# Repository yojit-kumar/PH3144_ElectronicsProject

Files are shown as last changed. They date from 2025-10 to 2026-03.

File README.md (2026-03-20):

# Precision Closed-Loop AC Power Controller using PID Algorithm

**Course:** PH3144 Electronics-I with Lab

**Status:** Finished (with incomplete code implementation)

A project to design and build a closed-loop AC power controller using a PID algorithm to deliver a precise, stable power output to a load.

## Team Members & Responsibilities
* **Uday Pratap Bais (20231267):** Hardware Lead (Electrical), Design Lead.
* **Yash Dadhwal (20231287):** Software Lead (Algorithm), Testing, Software Integration.
* **Yojit Kumar (20231289):** Hardware Lead (Electronics), Documentation Lead.

## Project Structure
* **/docs:** Contains all project documentation, including the report, component datasheets, and images.
* **/hardware:** Contains hardware design files (schematics, PCB layouts from KiCad).
* **/src:** Contains all Arduino source code, organized by testing phase.
* **/dump:** Put anything and everything we find before the finalizing of the project, It may later get sorted and moved to the relavant folders.

## Getting Started
1.  Clone the repository: `git clone https://github.com/yojit-kumar/PH3144_ElectronicsProject`
2.  Install the required Arduino libraries:
    * `EmonLib`
    * `LiquidCrystal_I2C`
    * `Adafruit_ADS1X15`
3. Use the calibiration codes in the `src/` directory to calibirate the measurement components
4. Run the test codes from the same directory.
---

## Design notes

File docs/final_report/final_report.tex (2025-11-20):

\documentclass[11pt]{article}

%Packages
\usepackage[a4paper, margin=1in]{geometry}

\usepackage{hyperref}
\usepackage{amsmath, amssymb}
\usepackage{siunitx}
\usepackage{romannum}

\usepackage{bookmark}
\usepackage{booktabs}
\usepackage{indentfirst}
\usepackage{multirow}
\usepackage{float}

\usepackage{titlesec}

\usepackage{graphicx}
\usepackage{subcaption}
\usepackage{tikz}
\usetikzlibrary{shapes.geometric, arrows, positioning}
\usepackage[american]{circuitikz}
\usepackage{listings}
\usepackage{xcolor}

\definecolor{codegreen}{rgb}{0,0.6,0}
\definecolor{codegray}{rgb}{0.5,0.5,0.5}
\definecolor{codepurple}{rgb}{0.58,0,0.82}
\definecolor{backcolour}{rgb}{0.95,0.95,0.92}

\lstdefinestyle{mystyle}{
    backgroundcolor=\color{backcolour},   
    commentstyle=\color{codegreen},
    keywordstyle=\color{magenta},
    numberstyle=\tiny\color{codegray},
    stringstyle=\color{codepurple},
    basicstyle=\ttfamily\footnotesize,
    breakatwhitespace=false,         
    breaklines=true,                 
    captionpos=b,                    
    keepspaces=true,                 
    numbers=left,                    
    numbersep=5pt,                  
    showspaces=false,                
    showstringspaces=false,
    showtabs=false,                  
    tabsize=2
}
\lstset{style=mystyle}

\newcommand*{\titleGP}{\begingroup
	\centering % Center all text
	\vspace*{\baselineskip} % White space at the top of the page

	\rule{\textwidth}{1.6pt}\vspace*{-\baselineskip}\vspace*{2pt} % Thick horizontal line
	\rule{\textwidth}{0.4pt}\\[\baselineskip] % Thin horizontal line
	{\LARGE Project Report}\\[0.2\baselineskip] % Title
	\rule{\textwidth}{0.4pt}\vspace*{-\baselineskip}\vspace{3.2pt} % Thin horizontal line
	\rule{\textwidth}{1.6pt}\\[2\baselineskip] % Thick horizontal line

	\vspace*{2in}
    
    	\Huge Precision Closed-Loop AC Power Controller using PID 
    	
	\vspace*{2in}

	\Large Name: Yojit Kumar\\
	\vspace*{0.2in}
	\Large Reg. No.: 20231289\\
	\vspace*{0.2in}
	\Large Course Code: PH3144\\
	\vspace*{0.2in}
	\Large Group: \#23\\

\endgroup}

\makeatletter
\let\latexps@plain\ps@plain
\newcommand{\frontmatter}{\let\ps@plain\ps@empty\pagestyle{empty}}
\newcommand{\mainmatter}{%
  \let\ps@plain\latexps@plain\pagestyle{plain}%
  \clearpage
  \pagenumbering{arabic}}
\makeatother

\begin{document}
\frontmatter
\titleGP
\clearpage

\mainmatter
\section{Introduction}
In any modern electric system, especially in labs, precise control over the power delivered to an electrical appliance/device is important for efficiency, stabilty and protection of devices. What we've tried to do is to precisely control the electrical power of any device. We are using a simple light bulb for the ease of demonstration. But in theory, we can implement this on any device connected to AC Mains.

Our device measures the current and voltage input for an electric load and allows us to fix a power in the working range of the appliance. We control this with a technique called \emph{phase-angle fired control}, where the firing  angle of a thyristor (Triac) is adjusted to control the portion of the AC Waveform delivered to the load.

For an electric bulb, this works as a dimmer for the system, allowing us to observe the difference. But a simple dimmer is an open-loop control, whilst we have implemented a closed-loop approach with help of \emph{PID}. You cannot ask the dimmer to set the bulb to run at $\SI{50}{\watt}$. You can only set it to 50\% effort, but you can't be sure. It is also susceptible to disturbances. If there is an increase in the voltage in the circuit, the dimmer doesn't know that, and the bulb will light brighter.

A closed-loop control is better because it uses the feedback to compare the result. We are constantly measuring the current and voltage to find the actual Power and compare it to the set-point to dynamically adjust the firing angle based on the feedback.

\section{Design}

\subsection{Block Diagram}
\begin{figure}[h!]
\centering
\begin{tikzpicture}[
    auto,
    block/.style={rectangle, draw, fill=blue!20, text width=6em, text centered, rounded corners, minimum height=4em},
    line/.style={draw, -latex'}
]

% Place the nodes
\node [block] (ui) {User Interface (UI)};
\node [block, right=2cm of ui] (arduino) {Controller (PID Logic)};
\node [block, below=2cm of arduino] (control) {AC Control System (Muscle)};
\node [block, right=2cm of arduino] (measure) {Measurement System (Senses)};
\node [block, below=2cm of measure] (load) {AC Load};

% Draw the lines (arrows)
\path [line] (ui) -- node [above] {Setpoint} (arduino);
\path [line] (arduino) -- node [left] {Control Signal} (control);
\path [line] (control) -- (load);
\path [line] (load) -- node [left] {Feedback} (measure);
\path [line] (measure) -- (arduino);

\end{tikzpicture}
\caption{Block Overview of the Closed-Loop Power Controller}
\label{fig:block_diagram}
\end{figure}

We divide our system into smaller task-specific parts to better understand our system. First is the User Interface (UI), it allows us to display the results and also fix a set-point for the system. The Controller (here Arduino) is the brain of the whole system, running the PID logic, and controlling all the other components of our project. The Measurement System consists of some simple sensors that allow us to take current and voltage measurements and send these to the Controller. The AC Control is the muscle of the system, it controls the parameters to maintain the set-point as dictated by the Controller.

\subsection{Hardware Design}

\begin{figure}[H]

\caption{KiCad Schematics for the whole working the circuit}
\end{figure}

\subsubsection{Measurement Module}
This module is responsible for providing the critical feedback to the controller. The major components of the measurement module are:
\begin{enumerate}
	\item \underline{ZMPT101B Voltage Sensor Module}

		This active module safely steps down the $230\si{\volt}$ AC mains voltage to a low-voltage, isolated AC sine wave. Its onboard op-amp circuit biases this signal around a $2.5\si{volt}$ DC offset, making it safe for the low-voltage components to read.

	\item \underline{SCT-013-030 Current Sensor}

		A non-invasive current transformer that clamps around the live wire. It outputs a small AC voltage that is directly proportional to the AC current flowing to the load. This signal is also biased at $2.5\si{\volt}$ using an external voltage divider.

	\item \underline{ADS1115 16-bit  ADC Module}

		This is a high-precision, 16-bit Analog-to-Digital Converter. It is connected to the Arduino via the I2C bus (A4/A5). The Arduino's built-in 10-bit ADC is too noisy and has insufficient resolution for a "precision" controller. The 16-bit ADS1115 provides high-accuracy, low-noise measurements.
\end{enumerate}

\subsubsection{AC Control Module (Muscle)}
This component is the  high-voltage part of the circuit that controls the power flow. The major components that make up the AC Control Module are:
\begin{enumerate}
	\item \underline{MOC3023M (Triac Driver Optocoupler)}

		This chip is the safe bridge between the Arduino and the Triac. It receives a low-voltage $5\si{\volt}$ "fire" command from the Arduino (on pin D7) and uses an internal light-activated switch to trigger the high-voltage Triac.
		
		This provides galvanic isolation. It is the most important safety component, creating a physical air gap between the $230\si{\volt}$ AC circuit and the 5V logic circuit, protecting the Arduino and the user from lethal voltage.
	
	\item \underline{BTA41600B (Triac)}

		This is the heavy-duty, high-power AC switch. When it receives the trigger signal from the MOC3023M, it "latches" ON and conducts current to the light bulb. It automatically turns itself OFF (resets) at the end of every AC half-cycle when the current drops to zero.

		This is the component that actually controls the power. By precisely timing when this switch is turned on within each $10\si{\milli\second}$ half-cycle, we can control the total energy delivered to the load.

	\item \underline{PC814 (AC-Input Optocoupler)}

		This chip functions as our Zero-Crossing Detector (ZCD). Its AC input side watches the sine wave from the step-down transformer. At the precise moment the wave crosses its center point, the optocoupler's internal LED turns off, and triggers the phototransistor on the output side. This interrupt signal pulls down the output PIN\_4 that is connected to $+\SI{5}{\volt}$ of the Arduino.

		This signal is connected to the Arduino's hardware interrupt pin (D2). It provides a perfect timing pulse 100 times per second, synchronizing the Arduino's code with the AC line.	
\end{enumerate}

\section{Methodology}
In order to control the high-voltage current passing through the load to precisely change the power. We are using \emph{Phase Angle Control} using the \textbf{Triac}. The method requires us to change the gate voltage to the triac to control the current through the heavy load.
\begin{figure}[hbt]
	\centering
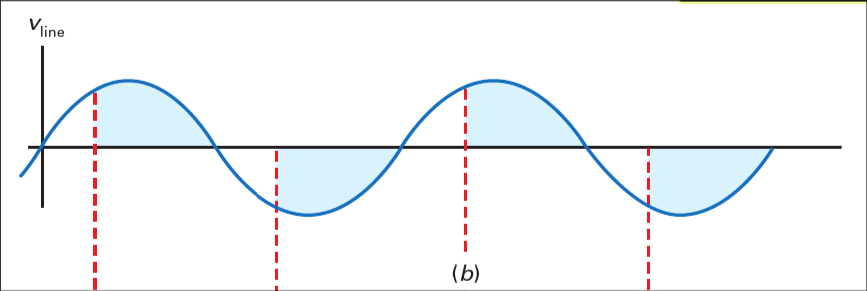
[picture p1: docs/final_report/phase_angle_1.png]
	
	\caption{Line voltage for the triac \emph{Ref: Malvino \& Bates Pg. 549}}
	\label{fig:phase_angle_1}
\end{figure}

\begin{figure}[hbt]
	\centering
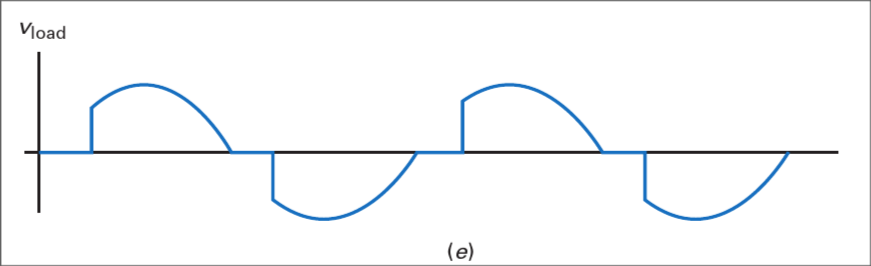
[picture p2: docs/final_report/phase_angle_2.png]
	
	\caption{Voltage across a load connected to the triac \emph{Ref: Malvino \& Bates Pg. 549}}
	\label{fig:phase_angle_2}
\end{figure}

\autoref{fig:phase_angle_1} shows the line voltage. When the triac is triggered, the triac starts conducting. It basically means the triac is on, and it will remain on until the line voltage goes back to zero then it turns off again. \autoref{fig:phase_angle_2} shows us the voltage across the load during this process. This turning on and off happens for every half-pulse of AC passing through the triac. Thus, the triac is switches its state around 200 times a second.

\begin{figure}[hbt]
	\centering
	\begin{subfigure}[t]{0.5\textwidth}	
		\centering
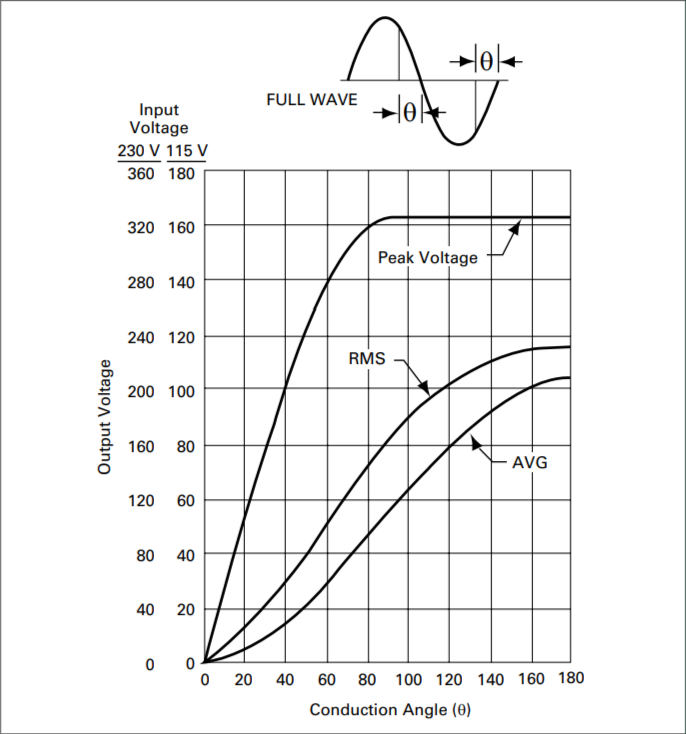
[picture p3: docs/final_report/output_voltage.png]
		
		\caption{Voltage of Full-Wave Phase Angle Control (Sinusodial)}
		\label{subfig:subfig_1}
	\end{subfigure}%
	\begin{subfigure}[t]{0.5\textwidth}
		\centering
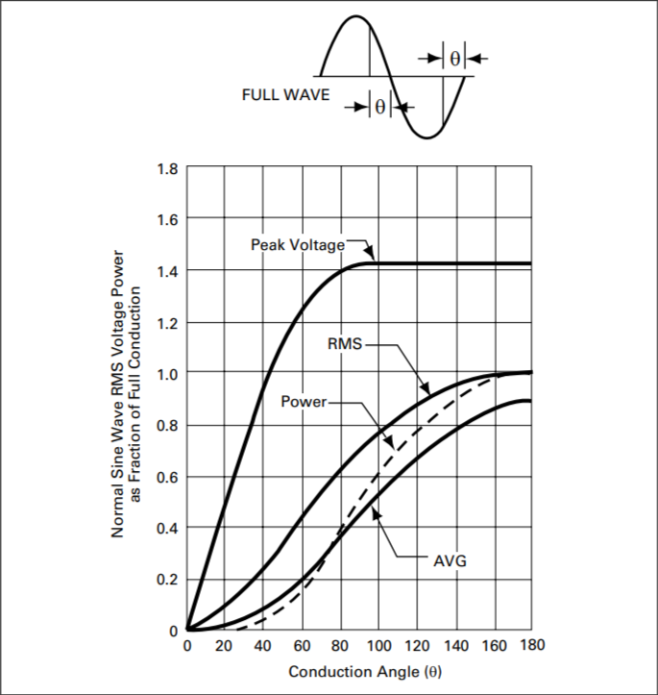
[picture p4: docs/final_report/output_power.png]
		
		\caption{Power of Full-Wave Phase Angle Control}
		\label{subfig:subfig_2}
	\end{subfigure}
	\caption{Voltage \& Power Curves for different $\theta$ \emph{Ref: Littlefuse AN1003 datasheet}} 
	\label{fig:power_curve}
\end{figure}

In \autoref{fig:power_curve}, $\theta$ is the conduction angle which is equivalent to $\pi - \theta_{\mathrm{firing}}$. $\theta_{\mathrm{firing}}$ is proportional to the firing delay. Thus, we can use the curves to study how the power or voltage may vary across the load as we change the firing delay.
But, as we are working with a closed-loop feedback system we don't need to refer to the curve, our algorithm is supposed to give us a correction just based on the error from the set point.

In order to find this error term, we need to find the real-time value of the power first. For which we are using a voltage sesing module (\emph{ZMPT101B}) and a current sensing module (\emph{SCT-013-030}), and both of these are connected to an external Analog-to-Digital Convertor(ADC) (\emph{ADS1115}) which is there to give us a better resolution than the onboard ADC of the Arduino Board.

Another important part of controlling the AC power and setting a firing delay is to actually know when the AC pulse starts. Because of how a triac functions it will auto turn-off at the end of each half cycle but we need to know the starting point. This starting point is detected using a zero-crossing detector that we have created using a step-down transformer and a AC input optocoupler (\emph{PC814}). We have also attached a basic I2C display to as a part of our user interface to display the power, voltage and current information in real-time.

\section{Implementation}

The project was designed with two separate perfboards:high-voltage perfboard as in \autoref{fig:high_voltage} and a low-voltage perfboard \autoref{fig:low_voltage}. This was created to keep in mind the safety of low volage components, and over safe handling of the project. We've also used optocouplers for the same reason; to create circuit isolation.

\begin{figure}[hbt]
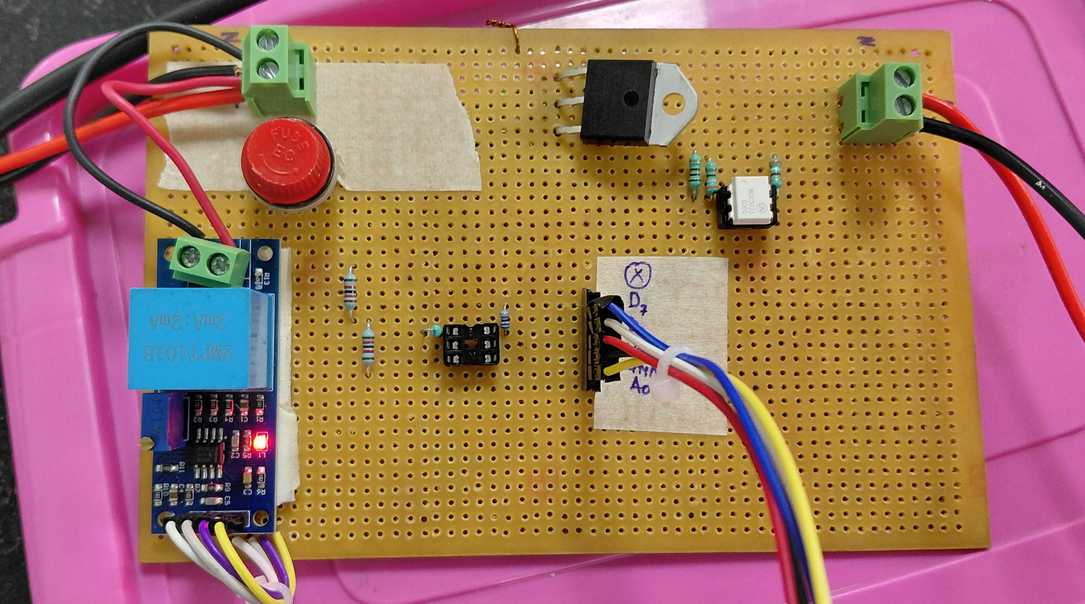
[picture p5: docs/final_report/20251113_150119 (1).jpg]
	
	\caption{\textbf{This is the high-voltage perfboard.} AC-In is from the left side which passes to the triac in the middle and load connected to the rightmost connetion point. Triac is connected to the \emph{MOC3023M} IC. The \emph{ZMPT101B} module at the left has a stepdown transformer visible to us as a blue cube. The empty IC base is supposed to hold the \emph{PC814} IC which is the AC input optocoupler, a part of the zero-crossing detector. All connections are soldered at the back and terminate at the jumper base in the middle, which we connect to the low voltage perfboard.}
	\label{fig:high_voltage}
\end{figure}

There is an extra component of the project on the breadboard as seen in \autoref{fig:zcd}. It is a zero-crossing detector made using \emph{PC814} IC and a bridge rectifier. The purpose of this circuit is to provide the required interrupt signal as seen in \autoref{fig:interrupt_signal}. This was created as a fix for a bug in our earlier designs. We will talk more on this in the debugging sections.

\begin{figure}[hbt]
	\begin{subfigure}[t]{0.45\textwidth}
	\flushleft
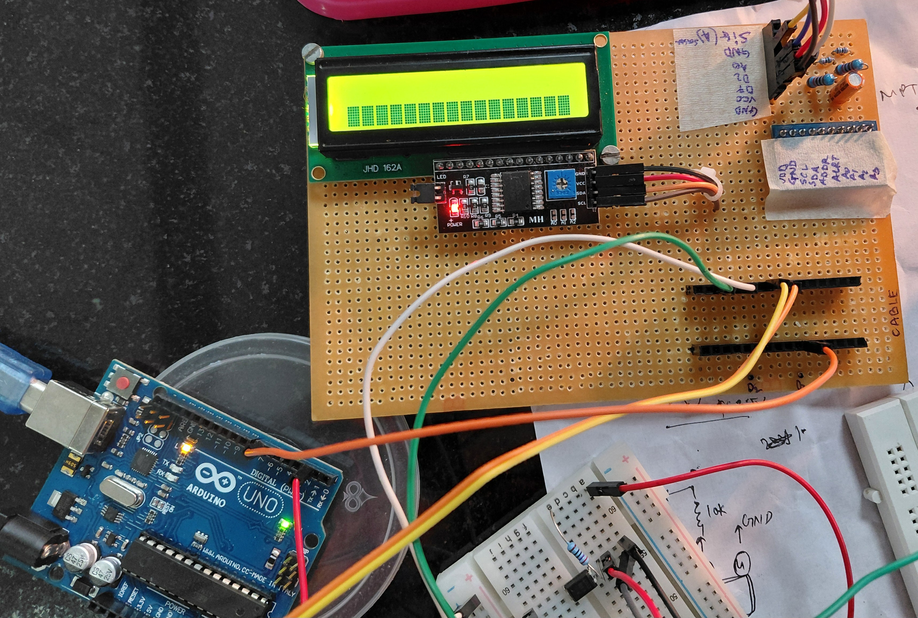
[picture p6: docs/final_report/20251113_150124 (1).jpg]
	
	\caption{\textbf{This is the low-voltage perfboard.} Jumper connections from the first perfboard and the current sensor module join at the top-right. There are voltage dividers and a clamper at the top for the ac-signal from the current-sensor module. The I2C display module is connected on top-left. And all connections terminate at the jumper base at the bottom, that connects to the \emph{Arduino UNO}}
	\label{fig:low_voltage}
	\end{subfigure}
	\hfill
	\begin{subfigure}[t]{0.45\textwidth}
	\flushright
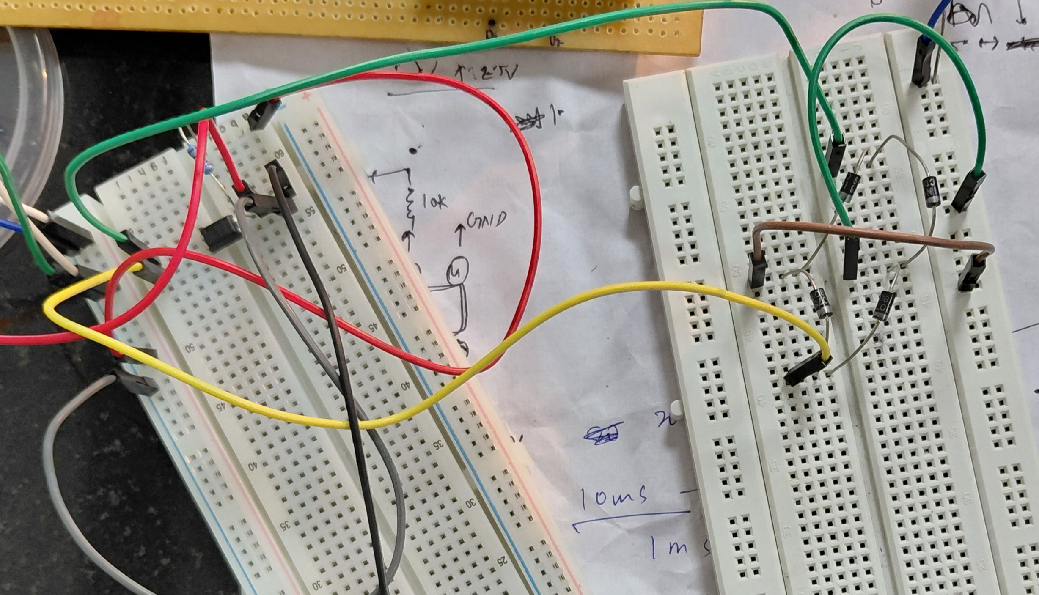
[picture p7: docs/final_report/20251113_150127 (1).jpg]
	
	\caption{This is the zero-crossing detector fix we created. The right breadboard has a bridge-rectifier which is connected to a voltage output of a stepdown 12V transformer. The rectified signal is passing to the \emph{PC814} IC on the breadboard at the right. This simply triggers at the start of each pulse half-cycle and sends a signal to the \emph{Arduino UNO}}
	\label{fig:zcd}
	\end{subfigure}
	\caption{Low-voltage Circuit}
\end{figure}

\begin{figure}[hbt]
	\centering
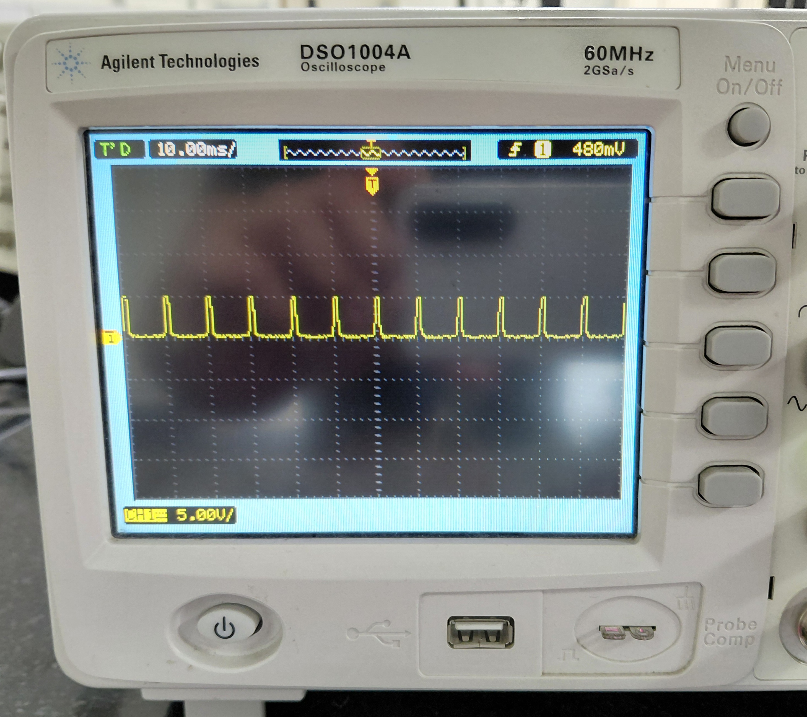
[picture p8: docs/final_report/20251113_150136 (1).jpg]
	
	\caption{This is the output for the interrupt signal from the zero-crossing detector being fired. We have a pulse/signal every $\SI{10}{\milli\second}$ as seen on the oscilloscope.}
	\label{fig:interrupt_signal}
\end{figure}

\section{Software}
The code that we've written for the project is in C++, it integrates all hardware components into a single, event-driven closed loop system.

We've have used some libraries for the operation of certain sensors, or simply the PID algorithm.

\begin{enumerate}
	\item \verb|<Wire.h>|: This is for the I2C communication, allowing us to use the \emph{ADS1115} and the LCD Display.

	\item \verb|<Adafruit_ADS1X15.h>|: It's a high level interface, specifically for the \emph{ADS1115} IC. It makes the process of setting a gain, and reading 16-bit analog values easier.

	\item \verb|<PID_v1.h>|: This is our robust, prebuilt PID algorithm, saving us development time.

	\item \verb|<Emonlib.h>|: This is to directly communicate with the \emph{SCT-013-030} current sensor module, when using the Arduino's inbuilt ADC.

	\item \verb|<ZMPT101B.h>|: This is for direct communicationwith the voltage sensing module,when using the Arduino's inbuilt ADC.
\end{enumerate}

We initialized the system with the \verb|setup()| function to configure the components before the main loop. \verb|ads.begin()| and the \verb|ads.setGain(GAIN_ONE)| to start the ADS and configures the full 16-bit resolution over a $\pm \SI{4.096}{\volt}$ range.

\noindent Next thing, we initialize is the PID controller. \verb|myPID.SetSampleTime(100)| tells the PID to run every $\SI{100}{\milli\second}$ and the main PID function is 

\noindent \verb|PID(&measurePower, &pidOutput, &setpointPower, Kp, Ki, Kd, REVERSE)|

A very important part of the code is the interrupt attachment done through: 

\noindent \verb|attachInterrupt(digitalPinToInterrupt(ZCD_PIN), onZeroCross, CHANGE)|. 
It tells the microcontroller to stop whatever it is doing and immediately run the \verb|onZeroCross()|

\noindent The main loop is structured to be non-blocking, ensuring that firing logic is never delayed.
\begin{lstlisting}[language=C++]
if (zcdFlag == true) {
	// Wait for the delay calculated by the PID
	delayMicroseconds(firingDelay);

	// Fire the Triac
	digitalWrite(TRIAC_PIN, HIGH);
	delayMicroseconds(20); // Short pulse
	digitalWrite(TRIAC_PIN, LOW);
	   
	zcdFlag = false; // Reset the flag
}
\end{lstlisting}
\noindent This is the most time-sensitive part of the code. It waits for the \verb|firingDelay| (calculated by the PID controller) and then sends a brief $\SI{20}{\micro\second}$ pulse to the \emph{MOC3023M}, triggering the Triac for that cycle.

Next we calculate the power using \verb|calculatePower()|. We run this function inside a \verb|millis()| timer. We run a \verb|for| loop that takes many sample readings from the ADC. We calculate the RMS value of current and voltage using these readings. And finally, we update the global \verb|measuredPower| variable, which the PID controller use.
\begin{lstlisting}[language=C++]
// --- FUNCTION TO CALCULATE POWER ---
void calculatePower() {
  // Use 64-bit integers to prevent overflow (the 'nan' bug)
  unsigned long long sumVoltageSq = 0;
  unsigned long long sumCurrentSq = 0;
  
  int16_t voltageSample;
  int16_t currentSample;

  for (int i = 0; i < sampleCount; i++) {
    voltageSample = ads.readADC_SingleEnded(VOLT_ADC_S);
    currentSample = ads.readADC_SingleEnded(CURR_ADC_S);

    long filteredVoltage = voltageSample - voltageOffset;
    long filteredCurrent = currentSample - currentOffset;

    sumVoltageSq += (unsigned long long)filteredVoltage*filteredVoltage;
    sumCurrentSq += (unsigned long long)filteredCurrent*filteredCurrent;
  }

  // Calculate RMS Voltage
  double meanVoltageSq = (double)sumVoltageSq / sampleCount;
  double rmsVoltageRaw = sqrt(meanVoltageSq);
  double Vrms = rmsVoltageRaw * ADS_VOLTS_PER_BIT * VOLTAGE_CAL;

  // Calculate RMS Current
  double meanCurrentSq = (double)sumCurrentSq / sampleCount;
  double rmsCurrentRaw = sqrt(meanCurrentSq);
  double Irms = rmsCurrentRaw * ADS_VOLTS_PER_BIT * CURRENT_CAL;

  // Update the global measuredPower variable
  measuredPower = Vrms * Irms;
}
\end{lstlisting}
Inside the same $\SI{100}{\milli\second}$ timer, after the power is calculated, the \verb|myPID.Compute()| function is called. This single command tells the PID library to:
\begin{enumerate}
	\item Read the \verb|measuredPower| (Input).
	\item Compare it to \verb|setpointPower| (Setpoint).
	\item Calculate the error.
	\item Run its internal P, I, and D logic.
	\item Update the \verb|pidOutput| (Output) variable.
\end{enumerate}
Immediately after, the code maps this new output to the \verb|firingDelay|. This mapping is inverted: a low PID output (0, for "min power") results in a long $\SI{9500}{\micro\second}$ delay, and a high PID output (255, for "max power") results in a short $\SI{1000}{\micro\second}$ delay. This is what steers the system toward the setpoint.
\section{Debugging}
\subsection{AC Control Failure}
During initial testing, the load (light bulb) failed to energize, even when the microcontroller sent a trigger signal.
\begin{itemize}
	\item{\textbf{Diagnostics:}} 
		A "Dumb Blinker" test sketch was developed to bypass the zero-crossing detector and trigger the triac blindly at a fixed interval. This isolated the fault to the \emph{MOC3023M}/Triac circuit.
		We verified the load by connecting it directly to mains (Passed). We probed the \emph{MOC3023M} input (Pin 1/2) with a multimeter. The Arduino was correctly delivering 1.2V during the "ON" state (Passed). Finally, we probed the \emph{MOC3023M} output (Pin 4/6). No conduction was detected despite the input signal. (Failed)
	\item{\textbf{Cause:}}
		The \emph{MOC3023M} optocoupler output stage had failed open. Further analysis of the initial soldering revealed that the gate current-limiting resistor ($\SI{470}{\ohm}$) was initially placed incorrectly, likely causing a massive current surge through the phototriac during the first power-up event.
	\item{\textbf{Solution:}}
		The \emph{MOC3023M} was replaced. The wiring was corrected to ensure the $\SI{470}{\ohm}$ resistor was placed strictly in series between the MOC output pin and the triac Gate to limit surge current to safe levels.
\end{itemize}
\subsection{Zero-Crossing Detection Failure}
The synchronization circuit proved to be the most complex subsystem to debug, requiring multiple iterations and component changes. Initially, the ZCD interrupt service routine never triggered, despite correct wiring. A manual examination of the IC revealed that the \emph{H11AA1} IC was dead, and due to unavailibilty of the same chip we obtained a \emph{PC814} IC as replacement. Even with replacement the system failed to achieve phase control. The interrupt service routine was either not firing or firing erratically only during power-on transients.
\begin{itemize}
	\item{\textbf{Diagnostics:}}
		An oscilloscope was used to visualize the analog output of the \emph{ZMPT101B} voltage sensor. We also used a function generator to replicate the signal from the voltage sensor module and then alter it to figure out the point of failure. We needed to overcome the forward voltage ($V_f \approx \SI{1.2}{\volt}$) of the optocoupler's internal LEDs.
	\item{\textbf{Cause:}}
		The signal was found to be biased at $\SI{2.5}{\volt}$ DC. The \emph{PC814} forward voltage was almost always getting exceeded by the signal because the signal oscillated between $\SI{1.5}{\volt}$ and $\SI{4}{\volt}$, it was always higher than $\SI{1.2}{\volt}$. This meant the \emph{PC814} was permanently forward-biased (ON), holding the interrupt pin LOW.
	\item{\textbf{Solution}}
		We replaced the \emph{ZMPT101B} module on the input side and replaced it with a step-down trasnformer of $230\si{\volt}$ to $12\si{\volt}$ kind. We connected the the center tap of the output side to the \emph{PC814} IC and provided a $6\si{\volt}$ peak signal. We also added multiple high wattage resistors before the IC so the signal not exceed the maximum forward current rating.
\end{itemize}
\subsection{Measurement \& ADC Integration}
RMS calculations for voltage and current were inaccurate or returning \verb|nan| (Not a Number) errors.
\begin{itemize}
	\item \textbf{Diagnostics:}
		After running for several seconds, the RMS value would become corrupted.
	\item \textbf{Cause:}
		The \verb|sumVoltageSq| variable, used to accumulate squared ADC samples, was declared as a \verb|long| (32-bit). With 500 samples of 16-bit squared data, the value exceeded the maximum limit ($2.1 \times 10^9$), causing an integer overflow to a negative value. Attempting to calculate the \verb|sqrt()| of this negative number resulted in \verb|nan|.
	\item \textbf{Solution:}
		Accumulator variables were promoted to \verb|unsigned long long| (64-bit) to prevent overflow.
\end{itemize}
\section{Results \& Discussion}
While we aimed to implement a fully integrated, real-time PID control loop, the final execution was constrained by the hardware resources of the microcontroller. However, extensive unit testing successfully validated the electronic design, the measurement accuracy, and the phase-control logic.

Before attempting full integration, individual modules were subjected to rigorous testing to verify their reliability. 
To verify the "Muscle" (\emph{MOC3023M} and \emph{BTA416}) and "Timing" (\emph{PC814} ZCD) circuits, a hard-coded delay test was performed. The system successfully triggered the Triac at precise intervals (e.g., $5000\si{\micro\second}$ after zero-crossing). The load (light bulb) maintained a stable, flicker-free brightness consistent with the firing angle. This confirmed that the ZCD interrupt was firing correctly at $100\si{\hertz}$ and the isolation circuit was functioning safely.
A "Looper" test code was implemented to sweep the firing delay from $1000\si{\micro\second}$ (Max Power) to $9000\si{\micro\second}$ (Min Power) and back. The bulb dimmed and brightened smoothly without stuttering or erratic flashing. This proved that the system could handle dynamic changes in firing angle in real-time, a prerequisite for PID control.
The sensing module was tested using the RMS calculation algorithm. The system successfully calculated \verb|Vrms|, \verb|Irms|, and \verb|Apparent Power|. The readings were compared against standard multimeter values. The 16-bit \emph{ADS1115} provided sufficient resolution to detect small changes in load current, validating the "Feedback" portion of the control loop.

The primary challenge encountered during the final phase was the integration of all software modules onto the Arduino Uno (ATmega328P). The Arduino Uno possesses only 2KB of Dynamic Memory (SRAM). The project required several memory-intensive libraries to run simultaneously. We understand that there might be some clever or more efficient ways to resolve this issue, but due to our groups inexperience in \emph{C++} proved to be a big obstacle in this. We had to chose to restric ourselves to only demonstrate the indivudual components of our project.

The original plan included testing the system with a Variac. By artificially lowering the input voltage (simulating a "brownout"), we intended to prove that the PID loop would automatically decrease the firing delay to maintain constant power at the bulb. Since the full PID loop could not run stably alongside the measurement code, this dynamic compensation could not be empirically verified. This validation test was not conducted at the end due to project timeline and limited resources.

Despite the integration setback, we believe that we have successfully delivered a professional-grade hardware platform. The hardware design, safety isolation features, and sensor calibration methods were proven effective. The electronic hardware is fully capable of supporting closed-loop control; the limitation lies strictly within the computational capacity of the chosen microcontroller.
\end{document}

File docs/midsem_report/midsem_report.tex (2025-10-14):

\documentclass[12pt]{article}

%Packages
\usepackage[a4paper, margin=1in]{geometry}
\usepackage{hyperref}
\usepackage{amsmath, amssymb}
\usepackage{booktabs}
\usepackage{indentfirst}
\usepackage{siunitx}
\usepackage{romannum}
\usepackage{multirow}
\usepackage{graphicx}
\usepackage{float}
\usepackage{titlesec}
\usepackage{tikz}
\usetikzlibrary{shapes.geometric, arrows, positioning}
\usepackage[american]{circuitikz}
\usepackage{bookmark}

\newcommand*{\titleGP}{\begingroup
	\centering % Center all text
	\vspace*{\baselineskip} % White space at the top of the page

	\rule{\textwidth}{1.6pt}\vspace*{-\baselineskip}\vspace*{2pt} % Thick horizontal line
	\rule{\textwidth}{0.4pt}\\[\baselineskip] % Thin horizontal line
	{\LARGE PH3144 | Electronics with Lab}\\[0.2\baselineskip] % Title
	\rule{\textwidth}{0.4pt}\vspace*{-\baselineskip}\vspace{3.2pt} % Thin horizontal line
	\rule{\textwidth}{1.6pt}\\[2\baselineskip] % Thick horizontal line

	\vspace*{1in}
    
    \LARGE Precision Closed-Loop AC Power Controller using PID 
    \vspace*{1in}\\
    
	\LARGE Group \#23\\
	\vspace*{1in}

	\Large Uday Pratap Bais (20231267)\\
	\vspace*{0.2in}
	\Large Yash Dadhwal (20231287)\\
	\vspace*{0.2in}
	\Large Yojit Kumar (20231289)\\
	\vspace*{0.2in}
\endgroup}

\makeatletter
\let\latexps@plain\ps@plain
\newcommand{\frontmatter}{\let\ps@plain\ps@empty\pagestyle{empty}}
\newcommand{\mainmatter}{%
  \let\ps@plain\latexps@plain\pagestyle{plain}%
  \clearpage
  \pagenumbering{arabic}}
\makeatother

\begin{document}
\frontmatter
\titleGP
\clearpage

\mainmatter
\section{Introduction}
\subsection{Background}
In modern electrical systems, precise control of power delivered to a load is essential for efficiency, stability, and protection of devices. One effective technique for regulating AC power is phase angle control, where the firing angle of a thyristor (SCR/triac) is adjusted to control the portion of the AC waveform delivered to the load. However, phase angle control by itself can lead to overshoot, slow response, or instability when load or input conditions vary.

To overcome these challenges, we propose the integration of a PID (Proportional– Integral– Derivative) controller. The PID algorithm dynamically adjusts the firing angle of the power electronics device based on feedback (such as load voltage, current, or power), ensuring that the output closely follows the desired setpoint. This combination allows us to achieve smooth, accurate, and stable power regulation in AC circuits.

\subsection{Objectives}
\begin{itemize}
\item Design and build a safe, isolated circuit for measuring real-time AC voltage and current.

\item Implement a phase angle control circuit using a Triac for regulating AC power.

\item Integrate these systems with an Arduino microcontroller.

\item Implement and tune a PID control algorithm to maintain a precise power setpoint.

\item Develop a user interface for setting the target power and viewing system status.
\end{itemize}

\section{Methodology}
%circuit diagrams and hardware implementation explanation
%logic diagrams and flowcharts

\subsection{Overview with Major Components}
\begin{figure}[h!]
\centering
\begin{tikzpicture}[
    auto,
    block/.style={rectangle, draw, fill=blue!20, text width=6em, text centered, rounded corners, minimum height=4em},
    line/.style={draw, -latex'}
]

% Place the nodes
\node [block] (ui) {User Interface (UI)};
\node [block, right=2cm of ui] (arduino) {Controller (PID Logic)};
\node [block, below=2cm of arduino] (control) {AC Control System (Muscle)};
\node [block, right=2cm of arduino] (measure) {Measurement System (Senses)};
\node [block, below=2cm of measure] (load) {AC Load};

% Draw the lines (arrows)
\path [line] (ui) -- node [above] {Setpoint} (arduino);
\path [line] (arduino) -- node [left] {Control Signal} (control);
\path [line] (control) -- (load);
\path [line] (load) -- node [left] {Feedback} (measure);
\path [line] (measure) -- (arduino);

\end{tikzpicture}
\caption{System Overview of the Closed-Loop Power Controller}
\label{fig:block_diagram}
\end{figure}

\subsection{Circuit Diagrams}
\subsubsection{User Interface}
\begin{figure}[H]
\centering
\begin{circuitikz}[scale=1.1, every node/.style={scale=0.9}]
    
    % Title
    \node at (6,8) {\textbf{User Interface Module}};
    
    % I2C LCD Display
    \draw[thick] (2,6) rectangle (8,7.5);
    \node at (5,6.75) {\textbf{16x2 I2C LCD Display}};
    
    % LCD Connection pins
    \draw (2,7.2) to[short, *-] ++(-1,0) node[left]{SCL};
    \draw (2,6.8) to[short, *-] ++(-1,0) node[left]{SDA};
    \draw (2,6.4) to[short, *-] ++(-1,0) node[left]{VCC (+5V)};
    \draw (2,6.0) to[short, *-] ++(-1,0) node[left]{GND};
    
    % Push Button Section
    \node at (5,4.5) {\textbf{Set Point Control Buttons}};
    
    % UP Button Circuit
    \draw (1,3.5) node[vcc](vcc_up){+5V} to[short] ++(1,0) 
          to[push button, l=UP] ++(2.5,0) coordinate(up_out);
    \draw (up_out) to[short, *-] ++(1.5,0) node[right]{D5};
    \draw (up_out) to[R, l=$R_1$ 10k$\Omega$] ++(0,-1) node[ground](gnd_up){};
    
    % DOWN Button Circuit  
    \draw (1,1.5) node[vcc](vcc_down){+5V} to[short] ++(1,0) 
          to[push button, l=DOWN] ++(2.5,0) coordinate(down_out);
    \draw (down_out) to[short, *-] ++(1.5,0) node[right]{To Arduino D6};
    \draw (down_out) to[R, l=$R_2$ 10k$\Omega$] ++(0,-1) node[ground](gnd_down){};
    
    % Arduino Connection Summary Box
    \draw[dashed] (9,2.5) rectangle (13,6);
    \node at (11,5.5) {\textbf{Arduino Connections}};
    \node at (11,5) [align=left] {SCL → A5};
    \node at (11,4.6) [align=left] {SDA → A4};
    \node at (11,4.2) [align=left] {UP Button → D5};
    \node at (11,3.8) [align=left] {DOWN Button → D6};
    \node at (11,3.4) [align=left] {VCC → +5V};
    \node at (11,3) [align=left] {GND → GND};
    
\end{circuitikz}
\caption{User Interface Module - LCD Display and Control Buttons}
\label{fig:ui_circuit_improved}
\end{figure}

\subsubsection{AC Control System}

\begin{figure}[H]
\centering
\begin{circuitikz}[scale=1, every node/.style={scale=0.7}]
    
    % HIGH VOLTAGE SECTION - AC Input Lines
    \draw (0,5) node[left]{230V AC Live} to[short] ++(1,0) coordinate(live_in);
    \draw (0,4) node[left]{230V AC Neutral} to[short] ++(1,0) coordinate(neutral_in);
    
    % BTA416 Triac - draw as box with three connections
    \draw (live_in) to[short] ++(1,0) to[short,-*] ++(0,1) coordinate(triac_input);
    \draw (1.5,6) rectangle ++(2,1) coordinate(triac_box);
    \node at ([xshift=-1cm, yshift=-0.5cm]triac_box) {BTA416};
    
    % Triac connections
    \draw (triac_input) ++(1,0) to[short,*-] ++(0,-1) to[short] ++(1,0) coordinate(load_in);
    \draw (triac_input) ++(0.5,0) to[short,*-] ++ (0,-3) coordinate(gate);
    
    % Connect triac terminals
    \draw (load_in) to[lamp] ++(3,0) coordinate(after_load);
    \draw (neutral_in) to[short] ++(6,0) to[short] ++(0,1) coordinate(neutral_after load);
    
    % LOW VOLTAGE SECTION - Arduino connections
    \draw (0,1.5) node[left]{A9} to[short] ++(1,0) coordinate(arduino_pin);
    \draw (0,1) node[left]{VCC} to[short] ++(1,0) coordinate(arduino_5v);
    \draw (0,0.5) node[left]{GND (Arduino)} to[short] ++(1,0) coordinate(arduino_gnd);
    
    % MOC3023M Optoisolator input
    \draw (arduino_pin) to[R=\SI{330}{\ohm}] ++(1,0) to[short,-*] ++(0.5,0) coordinate(led_anode);
    \draw (arduino_5v) to[short,-*] ++(1.5,0) coordinate(5v_in);
    \draw (arduino_gnd) to[short,-*] ++(1.5,0) coordinate(gnd_in);
    
    % MOC3023M Optoisolator - draw as box with side connections
    \draw ([yshift=0.5cm]led_anode) rectangle ++(2,-2) coordinate(opto_box);
    \node at ([xshift=1cm, yshift=-0.5cm]led_anode) {MOC3023M};

    % Output side connections (right side of box)
    \draw (5v_in) ++(2,0) to[short,*-] ++(0.5,0) to[short] ++(0,2) to[short] (gate);
    
\end{circuitikz}
\end{figure}

\subsubsection{Measurement System}
\begin{figure}[H]
\centering
\begin{circuitikz}[scale=1, every node/.style={scale=0.7}]
    
    % AC Input Lines
    \draw (0,8) node[left]{230V AC Live} to[short] ++(1,0) coordinate(live_in);
    \draw (0,7) node[left]{230V AC Neutral} to[short] ++(1,0) coordinate(neutral_in);
    
    % Section 1: ZMPT101B Voltage Module
    \draw[thick] (1,6.5) rectangle (4,8.5);
    \node at (2.5,7.8) {\textbf{ZMPT101B}};
    \node at (2.5,7) {\textbf{Voltage Module}};
    
    % ZMPT101B connections
    \draw (live_in) to[short] (0,8);
    \draw (neutral_in) to[short] (0,7);
    \draw (4,7.5) to[short] ++(1,0) coordinate(zmpt_out);
    \node at (4,7.7) [right] {Analog Out};
    \draw (5,7.5) to[short, *-] ++(0,-1) to[short,-*] ++(1,0) node[right] {A0};   
    
    % Section 2: SCT-013-030 Current Sensor
    \node at (4,4.5) {\textbf{SCT-013-030 Current Sensor}};
    
    % HIGH VOLTAGE SECTION - AC Input Lines (separated physically)
    \draw (0,3) node[left]{230V AC Live} to[short] ++(1,0) coordinate(live_in1);
    \draw (0,1.5) node[left]{230V AC Neutral} to[short] ++(1,0) coordinate(neutral_in1);
    
    % Live wire going to load (this is what the CT clamps around)
    \draw[ultra thick, red] (live_in1) to[short] ++(1,0) coordinate(live_to_load) 
          to[short] ++(2,0) coordinate(live_mid) to[lamp, l=Load] ++(3,0) 
          coordinate(live_after_load);
    \draw[thick, blue] (neutral_in1) to[short] ++(6,0) 
          to[short] ++(0,1.5) to[short] (live_after_load);
    
    % SCT-013-030 Current Transformer (clamps around live wire)
    \draw[thick] ([yshift=0.5cm]live_mid) arc (180:0:0.3) coordinate(ct_top_right);
    \draw[thick] ([yshift=-0.5cm]live_mid) arc (-180:0:0.3) coordinate(ct_bottom_right);
    \draw[thick] (ct_top_right) -- (ct_bottom_right);
    \node at ([yshift=-1cm]live_mid) {SCT-013-030};
    
    % LOW VOLTAGE SECTION - CT output leads (physically separated)
    \draw (ct_top_right) to[short] ++(0.5,0) coordinate(isolation_point1);
    \draw (ct_bottom_right) to[short] ++(0.5,0) coordinate(isolation_point2);
    
    % Jump across isolation barrier
    \draw (isolation_point1) to[short] ++(1,0) coordinate(ct_signal);
    \draw (isolation_point2) to[short] ++(0,-1) node[ground]{};
    
    % Voltage divider to create 2.5V DC offset
    \draw (ct_signal) to[short] ++(1.5,0) coordinate(signal_point);
    \draw (signal_point) to[short] ++(0,0.5) to[R, l=$R_1$ 10k$\Omega$] ++(0,1) 
          node[vcc](vcc1){+5V};
    \draw (signal_point) to[short] ++(0,-0.5) to[R, l=$R_2$ 10k$\Omega$] ++(0,-1) 
          node[ground](gnd1){};
    
    % Coupling capacitor and output
    \draw (signal_point) to[C, l=$C_1$ \SI{10}{\micro\farad},*-] ++(2,0) coordinate(arduino_current);
    \draw (arduino_current) to[short, -*] ++(1.5,0) node[right]{A1};
    
    % Section 3: Zero-Crossing Detector
    \node at (10.8,6) {\textbf{Zero-Crossing Detector}};
    
    % Input from ZMPT101B
    \draw (zmpt_out) to[short] ++(1,0) to[R, l=$R_{in}$ \SI{10}{\kilo\ohm}] ++(2,0) coordinate(zcd_input);
    
    % H11AA1 Optocoupler
    \draw[thick] (9.5,6.8) rectangle (11.5,8.2);
    \node at (10.5,7.5) {\textbf{H11AA1}};
    \draw (zcd_input) to[short] (9.5,7.5);
    \draw (9.5,7.1) to[short] ++(-0.5,0) to[short] ++(0,-1.5) node[ground]{};
    
    % Voltage divider for reference
    \draw (9,9) to[R, l=$R_3$ \SI{10}{\kilo\ohm}, *-] ++(2,0) node[vcc]{+5V};
    \draw (9,9) to[R, l=$R_4$ \SI{10}{\kilo\ohm}] ++(-2,0) node[ground]{};
    \draw (9,9) |- (9.5,7.9);
    
    % Output circuit
    \draw (11.5,7.9) to[short] ++(0.5,0) to[R, l=\SI{10}{\kilo\ohm}] ++(0,1.5) node[vcc, label=left:+5V]{};
    \draw (11.5,7.1) to[short] ++(1,0) to[short] ++(0,-1.5) node[ground]{};
    \draw (11.5,7.5) to[short, -*] ++(1,0) node[right]{A2};
    
    % Arduino connections summary
    \draw[dashed] (9.2,1.2) rectangle (13,3);
    \node at (11,2.8) {\textbf{Arduino Connections}};
    \node at (11.3,2) [align=left] {A0: Voltage Signal \\ A1: Current Signal \\ A2: Zero-Cross Interrupt};

\end{circuitikz}
\caption{Measurement and Timing Module Schematic}
\label{fig:complete_measurement_module_improved}
\end{figure}

\section{Challenges \& Troubleshooting strategy}
\subsection{Safety}
The project involves working with AC mains supply, which introduces several safety concerns. The foremost challenge is high voltage exposure, since direct contact with live components can cause severe electric shock or injury. To mitigate this, all high-voltage sections are enclosed, and isolation is provided between the control and power circuits.

Short circuits and overcurrent conditions are also possible due to load faults or wiring errors, leading to damaging current surges. To counter this, fuses and circuit breakers are employed to protect the circuit from catastrophic failure. Similarly, improper isolation between the high-voltage power stage and the low-voltage control circuitry poses the risk of leakage currents reaching the user or microcontroller. This issue is minimized by using opto-isolators, isolation transformers, and careful PCB layout design.

Another important aspect is the misuse or rating exceedance of components, where devices such as SCRs, triacs, or resistors may fail if operated beyond their current, voltage, or thermal limits. To avoid this, all components are chosen with appropriate safety margins.
\subsection{PID tuning}
Tuning a PID controller for AC power regulation using phase angle control presents several challenges. One of the main difficulties is the nonlinear relationship between firing angle and load power, since PID control generally assumes a linear system model. This mismatch makes it harder to achieve stable tuning. Another issue arises from system delays, particularly with inductive loads, which introduce phase lag and can cause oscillations or instability in the response. In addition, there is significant coupling between the parameters $K_p$, $K_i$, and $K_d$, such that adjusting one parameter often changes the effect of the others, making the tuning process less straightforward. The system is also vulnerable to noise in feedback signals, as voltage and current sensors can pick up switching noise from SCR or triac operations, which is especially problematic for the derivative term that tends to amplify high-frequency noise. Another challenge is integral windup, where prolonged errors cause the integral term to accumulate excessively, leading to overshoot and sluggish recovery. Finally, the controller’s performance can vary significantly under different load types, since gains tuned for resistive loads may not be suitable for inductive loads that respond more slowly.

\section{Summary}
This project undertakes the design and implementation of a Precision Closed-Loop AC Power Controller. Standard open-loop AC control methods, such as simple dimmers, are susceptible to inaccuracies caused by fluctuations in mains voltage and changing load conditions. To overcome this, our system will employ a closed-loop feedback mechanism driven by a Proportional-Integral-Derivative (PID) control algorithm.

The primary objective is to create a robust and stable system capable of maintaining a user-defined power setpoint with high precision, demonstrating a practical application of control theory in modern power electronics. Safety is a paramount design consideration, addressed through galvanic isolation between low-voltage logic and high-voltage power circuits.
\end{document}

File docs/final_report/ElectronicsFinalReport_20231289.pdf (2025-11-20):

## Project Report

# Precision Closed-Loop AC Power Controller using PID

## Name: Yojit Kumar

## Reg. No.: 20231289

## Course Code: PH3144

## Group: #23

## 1 Introduction

In any modern electric system, especially in labs, precise control over the power delivered to an electrical appliance/device is important for efficiency, stabilty and protection of devices. What we’ve tried to do is to precisely control the electrical power of any device. We are using a simple light bulb for the ease of demonstration. But in theory, we can implement this on any device connected to AC Mains.
Our device measures the current and voltage input for an electric load and allows us to fix a power in the working range of the appliance. We control this with a technique called phase-angle fired control, where the firing angle of a thyristor (Triac) is adjusted to control the portion of the AC Waveform delivered to the load.
For an electric bulb, this works as a dimmer for the system, allowing us to observe the difference. But a simple dimmer is an open-loop control, whilst we have implemented a closed-loop approach with help of PID. You cannot ask the dimmer to set the bulb to run at 50W. You can only set it to 50% effort, but you can’t be sure. It is also susceptible to disturbances. If there is an increase in the voltage in the circuit, the dimmer doesn’t know that, and the bulb will light brighter.
A closed-loop control is better because it uses the feedback to compare the result. We are constantly measuring the current and voltage to find the actual Power and compare it to the set-point to dynamically adjust the firing angle based on the feedback.

## 2 Design

### 2.1 Block Diagram

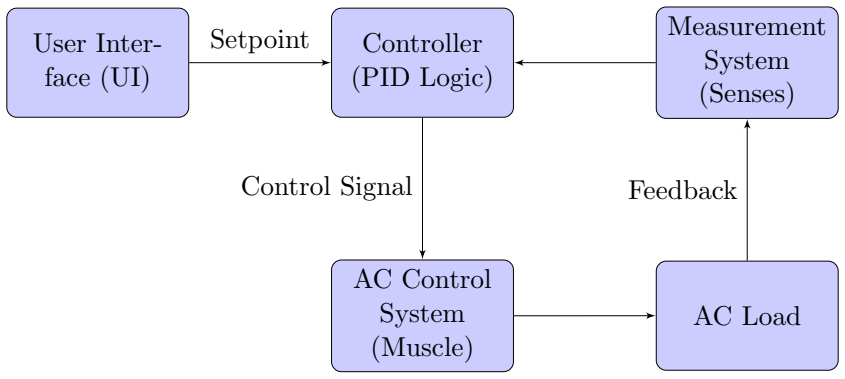
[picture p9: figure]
User Inter- face (UI); Controller (PID Logic); AC Control System (Muscle); Measurement System (Senses); AC Load; Setpoint; Control Signal; Feedback

Figure 1: Block Overview of the Closed-Loop Power Controller

We divide our system into smaller task-specific parts to better understand our system. First is the User Interface (UI), it allows us to display the results and also fix a set-point for the system. The Controller (here Arduino) is the brain of the whole system, running the PID logic, and controlling all the other components of our project. The Measurement System consists of some simple sensors that allow us to take current and voltage measurements and send these to the Controller. The AC Control is the muscle of the system, it controls the parameters to maintain the set-point as dictated by the Controller.

2.2 | Hardware Design 1 | 2 | 3 | 4 | 5 | 6
1 | 2 | 3 | 4 | 5 | 6

A

BC

D

A

BC

D Date: 2025-11-01 KiCad E.D.A. 9.0.6 Size: A4 | Rev: 1.1

Id: 1/1 Title: AC_Power_Controller File: AC_Power_Controller.kicad_sch Sheet: /

+5V GND

2

1

3

4 U4PC814

3

2 | 1 TRI1 BTA41-600BRG

GND

R8
þÿ10K©

+5V

+5V GND

F1
1A

2

1

3

4

5 T1Transformer_230V_12V

1

2

J1
230VAC_IN | GND 1 VCC 2 SDA 3 SCL | 4

LCD1

16x2_I2C_LCD

R3
þÿ10K©
R4
þÿ10K©

R1
þÿ470©

1

2

6

4 U1 MOC3023M

GNDGND

R2

þÿ330© GND | D⁰/RX ¹⁵ D¹/TX ¹⁶ D² ¹⁷ D³ ¹⁸ D⁴ ¹⁹ D⁵ ²⁰ D⁶ ²¹ D⁷ ²² D⁸ ²³ D⁹ ²⁴ D¹⁰ ²⁵ D¹¹ ²⁶ D¹² ²⁷ D¹³ ²⁸ | VIN 8 GND 29 GND 6
3V3 4 GND 7 | +5V 5 ~{RESET} 3 IOREF

2 AREF 30 A0

9 A1 10 A2 11 A3 12 SDA/A4 13 SCL/A5 14 A1 Arduino_UNO_R2 GND GND GND
1 SIG

2 U5SCT_013_030

LA1
Lamp 200W

R5
þÿ10K©

+5V

+5V GND

6 AC_N

2 GND

5 OUT

4 AC_L

1 VCC
3 U3 ZMPT101B C1
þÿ10µF
+5V R6
þÿ10K© GND AIN⁰

4 AIN1

5 AIN2

6 AIN3

7 VDD 8 GND 3 ALERT/RDY

2 SCL 10 SDA

9 ADDR

1 U2 ADS1115IDGS U5SCT_013_030 GND

1 SIG
2 C1
þÿ10µF | R5
| þÿ10K©

+5V GND

U2 AIN⁰ | ADS1115IDGS

4 AIN1

5 AIN2

6 AIN3

7 VDD 8 GND 3 ALERT/RDY

2 SCL 10 SDA

9 ADDR

1 R6
þÿ10K©

+5V

+5V U3 ZMPT101B GND

6 AC_N

2 GND

5 OUT

4 AC_L

1 VCC

3 GND

R8
þÿ10K©

+5V

+5V R3

þÿ10K©
R4
þÿ10K© GNDGND

R2

þÿ330© GND | GND Figure 2: KiCad Schematics for the whole working the circuit

### 2.2.1 Measurement Module

This module is responsible for providing the critical feedback to the controller. The major components of the measurement module are:

1. ZMPT101B Voltage Sensor Module

This active module safely steps down the 230V AC mains voltage to a low-voltage, isolated AC sine wave. Its onboard op-amp circuit biases this signal around a 2.5volt DC offset, making it safe for the low-voltage components to read.

2. SCT-013-030 Current Sensor

A non-invasive current transformer that clamps around the live wire. It outputs a small AC voltage that is directly proportional to the AC current flowing to the load. This signal is also biased at 2.5V using an external voltage divider.

3. ADS1115 16-bit ADC Module

This is a high-precision, 16-bit Analog-to-Digital Converter. It is connected to the Arduino via the I2C bus (A4/A5). The Arduino’s built-in 10-bit ADC is too noisy and has insufficient resolution for a ”precision” controller. The 16-bit ADS1115 provides high-accuracy, low-noise measurements.

### 2.2.2 AC Control Module (Muscle)

This component is the high-voltage part of the circuit that controls the power flow. The major components that make up the AC Control Module are:

1. MOC3023M (Triac Driver Optocoupler)

This chip is the safe bridge between the Arduino and the Triac. It receives a low-voltage 5V ”fire” command from the Arduino (on pin D7) and uses an internal light-activated switch to trigger the high-voltage Triac.

This provides galvanic isolation. It is the most important safety component, creating a physical air gap between the 230V AC circuit and the 5V logic circuit, protecting the Arduino and the user from lethal voltage.

2. BTA41600B (Triac)

This is the heavy-duty, high-power AC switch. When it receives the trigger signal from the MOC3023M, it ”latches” ON and conducts current to the light bulb. It automatically turns itself OFF (resets) at the end of every AC half-cycle when the current drops to zero.

This is the component that actually controls the power. By precisely timing when this switch is turned on within each 10ms half-cycle, we can control the total energy delivered to the load.

3. PC814 (AC-Input Optocoupler)

This chip functions as our Zero-Crossing Detector (ZCD). Its AC input side watches the sine wave from the step-down transformer. At the precise moment the wave crosses its center point, the optocoupler’s internal LED turns off, and triggers the phototransistor on the output side. This interrupt signal pulls down the output PIN 4 that is connected to +5 V of the Arduino.

This signal is connected to the Arduino’s hardware interrupt pin (D2). It provides a perfect timing pulse 100 times per second, synchronizing the Arduino’s code with the AC line.

## 3 Methodology

In order to control the high-voltage current passing through the load to precisely change the power. We are using Phase Angle Control using the Triac. The method requires us to change the gate voltage to the triac to control the current through the heavy load.


Figure 3: Line voltage for the triac Ref: Malvino & Bates Pg. 549

Figure 3 shows the line voltage. When the triac is triggered, the triac starts conducting. It basically means the triac is on, and it will remain on until the line voltage goes back to zero then it turns off again. Figure 4 shows us the voltage across the load during this process. This

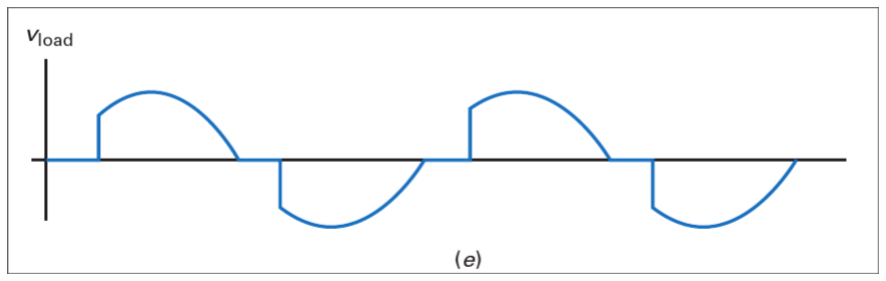
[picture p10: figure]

Figure 4: Voltage across a load connected to the triac Ref: Malvino & Bates Pg. 549

turning on and off happens for every half-pulse of AC passing through the triac. Thus, the triac is switches its state around 200 times a second.

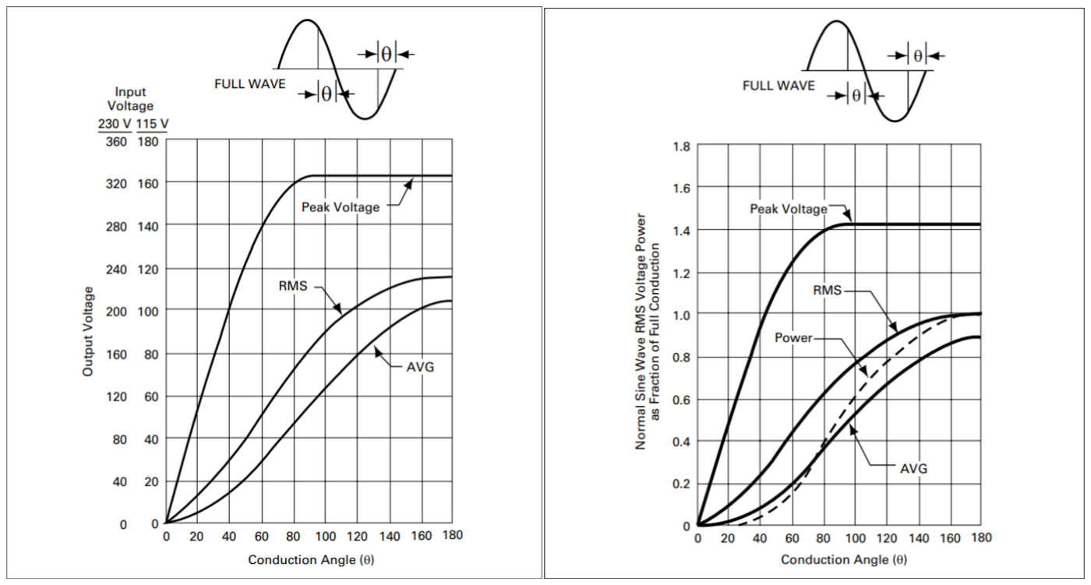
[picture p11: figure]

(a) Voltage of Full-Wave Phase Angle Control (Sinusodial)
(b) Power of Full-Wave Phase Angle Control

Figure 5: Voltage & Power Curves for different θ Ref: Littlefuse AN1003 datasheet

In Figure 5, θ is the conduction angle which is equivalent to π −θfiring. θfiring is proportional to the firing delay. Thus, we can use the curves to study how the power or voltage may vary across the load as we change the firing delay. But, as we are working with a closed-loop feedback system we don’t need to refer to the curve, our algorithm is supposed to give us a correction just based on the error from the set point.
In order to find this error term, we need to find the real-time value of the power first. For which we are using a voltage sesing module (ZMPT101B) and a current sensing module (SCT-013-030 ), and both of these are connected to an external Analog-to-Digital Convertor(ADC) (ADS1115 ) which is there to give us a better resolution than the onboard ADC of the Arduino Board.
Another important part of controlling the AC power and setting a firing delay is to actually know when the AC pulse starts. Because of how a triac functions it will auto turn-off at the end of each half cycle but we need to know the starting point. This starting point is detected using a zero-crossing detector that we have created using a step-down transformer and a AC input optocoupler (PC814 ). We have also attached a basic I2C display to as a part of our user interface to display the power, voltage and current information in real-time.

## 4 Implementation

The project was designed with two separate perfboards:high-voltage perfboard as in Figure 6 and a low-voltage perfboard Figure 7a. This was created to keep in mind the safety of low volage components, and over safe handling of the project. We’ve also used optocouplers for the same reason; to create circuit isolation.


Figure 6: This is the high-voltage perfboard. AC-In is from the left side which passes to the triac in the middle and load connected to the rightmost connetion point. Triac is connected to the MOC3023M IC. The ZMPT101B module at the left has a stepdown transformer visible to us as a blue cube. The empty IC base is supposed to hold the PC814 IC which is the AC input optocoupler, a part of the zero-crossing detector. All connections are soldered at the back and terminate at the jumper base in the middle, which we connect to the low voltage perfboard.

There is an extra component of the project on the breadboard as seen in Figure 7b. It is a zero-crossing detector made using PC814 IC and a bridge rectifier. The purpose of this circuit is to provide the required interrupt signal as seen in Figure 8. This was created as a fix for a bug in our earlier designs. We will talk more on this in the debugging sections.

## 5 Software

The code that we’ve written for the project is in C++, it integrates all hardware components into a single, event-driven closed loop system.
We’ve have used some libraries for the operation of certain sensors, or simply the PID algorithm.
1. <Wire.h>: This is for the I2C communication, allowing us to use the ADS1115 and the LCD Display.
2. <Adafruit_ADS1X15.h>: It’s a high level interface, specifically for the ADS1115 IC. It makes the process of setting a gain, and reading 16-bit analog values easier.


(a) This is the low-voltage perfboard. Jumper connections from the first perfboard and the current sensor module join at the topright. There are voltage dividers and a clamper at the top for the ac-signal from the currentsensor module. The I2C display module is connected on top-left. And all connections terminate at the jumper base at the bottom, that connects to the Arduino UNO


(b) This is the zero-crossing detector fix we created. The right breadboard has a bridgerectifier which is connected to a voltage output of a stepdown 12V transformer. The rectified signal is passing to the PC814 IC on the breadboard at the right. This simply triggers at the start of each pulse half-cycle and sends a signal to the Arduino UNO

Figure 7: Low-voltage Circuit

3. <PID_v1.h>: This is our robust, prebuilt PID algorithm, saving us development time.
4. <Emonlib.h>: This is to directly communicate with the SCT-013-030 current sensor module, when using the Arduino’s inbuilt ADC.
5. <ZMPT101B.h>: This is for direct communicationwith the voltage sensing module,when using the Arduino’s inbuilt ADC.

We initialized the system with the setup() function to configure the components before the main loop. ads.begin() and the ads.setGain(GAIN_ONE) to start the ADS and configures the full 16-bit resolution over a ±4.096 V range.
Next thing, we initialize is the PID controller. myPID.SetSampleTime(100) tells the PID to run every 100 ms and the main PID function is
PID(&measurePower, &pidOutput, &setpointPower, Kp, Ki, Kd, REVERSE)
A very important part of the code is the interrupt attachment done through: attachInterrupt(digitalPinToInterrupt(ZCD_PIN), onZeroCross, CHANGE). It tells the microcontroller to stop whatever it is doing and immediately run the onZeroCross()
The main loop is structured to be non-blocking, ensuring that firing logic is never delayed.
1 | if ( zcdFlag == true ) {
2 | // Wait for the delay calculated by the PID
3 | delayMicroseconds ( firingDelay ) ;

4
5 | // Fire the Triac
6 | digitalWrite ( TRIAC_PIN , HIGH ) ;
7 | delayMicroseconds (20) ; // Short pulse
8 | digitalWrite ( TRIAC_PIN , LOW ) ;

9
10 | zcdFlag = false ; // Reset the flag
11 | }

This is the most time-sensitive part of the code. It waits for the firingDelay (calculated by the PID controller) and then sends a brief 20 µs pulse to the MOC3023M, triggering the Triac for that cycle.
Next we calculate the power using calculatePower(). We run this function inside a millis() timer. We run a for loop that takes many sample readings from the ADC. We


Figure 8: This is the output for the interrupt signal from the zero-crossing detector being fired. We have a pulse/signal every 10 ms as seen on the oscilloscope.

calculate the RMS value of current and voltage using these readings. And finally, we update the global measuredPower variable, which the PID controller use.

1 | // --- FUNCTION TO CALCULATE POWER ---
2 | void calculatePower () {
3 | // Use 64 - bit integers to prevent overflow (the ’nan ’ bug)
4 | unsigned long long sumVoltageSq = 0;
5 | unsigned long long sumCurrentSq = 0;

6
7 | int16_t voltageSample ;
8 | int16_t currentSample ;

9
10 | for (int i = 0; i < sampleCount ; i ++) {
11 | voltageSample = ads . readADC_SingleEnded ( VOLT_ADC_S ) ;
12 | currentSample = ads . readADC_SingleEnded ( CURR_ADC_S ) ;

13
14 | long filteredVoltage = voltageSample - voltageOffset ;
15 | long filteredCurrent = currentSample - currentOffset ;

16
17 | sumVoltageSq += ( unsigned long long ) filteredVoltage * filteredVoltage ;
18 | sumCurrentSq += ( unsigned long long ) filteredCurrent * filteredCurrent ;
19 | }

20
21 | // Calculate RMS Voltage
22 | double meanVoltageSq = ( double ) sumVoltageSq / sampleCount ;
23 | double rmsVoltageRaw = sqrt ( meanVoltageSq ) ;
24 | double Vrms = rmsVoltageRaw * ADS_VOLTS_PER_BIT * VOLTAGE_CAL ;

25
26 | // Calculate RMS Current
27 | double meanCurrentSq = ( double ) sumCurrentSq / sampleCount ;
28 | double rmsCurrentRaw = sqrt ( meanCurrentSq ) ;
29 | double Irms = rmsCurrentRaw * ADS_VOLTS_PER_BIT * CURRENT_CAL ;

30
31 | // Update the global measuredPower variable
32 | measuredPower = Vrms * Irms ;
33 | }

Inside the same 100 ms timer, after the power is calculated, the myPID.Compute() function is called. This single command tells the PID library to:

1. Read the measuredPower (Input).

2. Compare it to setpointPower (Setpoint).
3. Calculate the error.
4. Run its internal P, I, and D logic.
5. Update the pidOutput (Output) variable.

Immediately after, the code maps this new output to the firingDelay. This mapping is inverted: a low PID output (0, for ”min power”) results in a long 9500 µs delay, and a high PID output (255, for ”max power”) results in a short 1000 µs delay. This is what steers the system toward the setpoint.

## 6 Debugging

### 6.1 AC Control Failure

During initial testing, the load (light bulb) failed to energize, even when the microcontroller sent a trigger signal.

- Diagnostics: A ”Dumb Blinker” test sketch was developed to bypass the zero-crossing detector and trigger the triac blindly at a fixed interval. This isolated the fault to the MOC3023M /Triac circuit. We verified the load by connecting it directly to mains (Passed). We probed the MOC3023M input (Pin 1/2) with a multimeter. The Arduino was correctly delivering 1.2V during the ”ON” state (Passed). Finally, we probed the MOC3023M output (Pin 4/6). No conduction was detected despite the input signal. (Failed)
- Cause: The MOC3023M optocoupler output stage had failed open. Further analysis of the initial soldering revealed that the gate current-limiting resistor (470 Ω) was initially placed incorrectly, likely causing a massive current surge through the phototriac during the first power-up event.
- Solution: The MOC3023M was replaced. The wiring was corrected to ensure the 470 Ω resistor was placed strictly in series between the MOC output pin and the triac Gate to limit surge current to safe levels.

### 6.2 Zero-Crossing Detection Failure

The synchronization circuit proved to be the most complex subsystem to debug, requiring multiple iterations and component changes. Initially, the ZCD interrupt service routine never triggered, despite correct wiring. A manual examination of the IC revealed that the H11AA1 IC was dead, and due to unavailibilty of the same chip we obtained a PC814 IC as replacement. Even with replacement the system failed to achieve phase control. The interrupt service routine was either not firing or firing erratically only during power-on transients.

- Diagnostics: An oscilloscope was used to visualize the analog output of the ZMPT101B voltage sensor. We also used a function generator to replicate the signal from the voltage sensor module and then alter it to figure out the point of failure. We needed to overcome the forward voltage (Vf ≈ 1.2 V) of the optocoupler’s internal LEDs.
- Cause: The signal was found to be biased at 2.5 V DC. The PC814 forward voltage was almost always getting exceeded by the signal because the signal oscillated between 1.5 V and 4 V, it was always higher than 1.2 V. This meant the PC814 was permanently forward-biased (ON), holding the interrupt pin LOW.

- Solution We replaced the ZMPT101B module on the input side and replaced it with a step-down trasnformer of 230V to 12V kind. We connected the the center tap of the output side to the PC814 IC and provided a 6V peak signal. We also added multiple high wattage resistors before the IC so the signal not exceed the maximum forward current rating.

### 6.3 Measurement & ADC Integration

RMS calculations for voltage and current were inaccurate or returning nan (Not a Number) errors.

- Diagnostics: After running for several seconds, the RMS value would become corrupted.
- Cause: The sumVoltageSq variable, used to accumulate squared ADC samples, was declared as a long (32-bit). With 500 samples of 16-bit squared data, the value exceeded the maximum limit (2.1×10⁹
), causing an integer overflow to a negative value. Attempting to calculate the sqrt() of this negative number resulted in nan.
- Solution: Accumulator variables were promoted to unsigned long long (64-bit) to prevent overflow.

## 7 Results & Discussion

While we aimed to implement a fully integrated, real-time PID control loop, the final execution was constrained by the hardware resources of the microcontroller. However, extensive unit testing successfully validated the electronic design, the measurement accuracy, and the phase-control logic.
Before attempting full integration, individual modules were subjected to rigorous testing to verify their reliability. To verify the ”Muscle” (MOC3023M and BTA416 ) and ”Timing” (PC814 ZCD) circuits, a hard-coded delay test was performed. The system successfully triggered the Triac at precise intervals (e.g., 5000µs after zero-crossing). The load (light bulb) maintained a stable, flicker-free brightness consistent with the firing angle. This confirmed that the ZCD interrupt was firing correctly at 100Hz and the isolation circuit was functioning safely. A ”Looper” test code was implemented to sweep the firing delay from 1000µs (Max Power) to 9000µs (Min Power) and back. The bulb dimmed and brightened smoothly without stuttering or erratic flashing. This proved that the system could handle dynamic changes in firing angle in real-time, a prerequisite for PID control. The sensing module was tested using the RMS calculation algorithm. The system successfully calculated Vrms, Irms, and Apparent Power. The readings were compared against standard multimeter values. The 16-bit ADS1115 provided sufficient resolution to detect small changes in load current, validating the ”Feedback” portion of the control loop.
The primary challenge encountered during the final phase was the integration of all software modules onto the Arduino Uno (ATmega328P). The Arduino Uno possesses only 2KB of Dynamic Memory (SRAM). The project required several memory-intensive libraries to run simultaneously. We understand that there might be some clever or more efficient ways to resolve this issue, but due to our groups inexperience in C++ proved to be a big obstacle in this. We had to chose to restric ourselves to only demonstrate the indivudual components of our project. The original plan included testing the system with a Variac. By artificially lowering the input voltage (simulating a ”brownout”), we intended to prove that the PID loop would automatically decrease the firing delay to maintain constant power at the bulb. Since the full PID loop could not run stably alongside the measurement code, this dynamic compensation could not be empirically verified. This validation test was not conducted at the end due to project timeline and limited resources.

Despite the integration setback, we believe that we have successfully delivered a professionalgrade hardware platform. The hardware design, safety isolation features, and sensor calibration methods were proven effective. The electronic hardware is fully capable of supporting closed-loop control; the limitation lies strictly within the computational capacity of the chosen microcontroller.

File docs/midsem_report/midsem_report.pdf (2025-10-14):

# PH3144 — Electronics with Lab

# Precision Closed-Loop AC Power Controller using PID

# Group #23

## Uday Pratap Bais (20231267)

## Yash Dadhwal (20231287)

## Yojit Kumar (20231289)

## 1 Introduction

### 1.1 Background

In modern electrical systems, precise control of power delivered to a load is essential for efficiency, stability, and protection of devices. One effective technique for regulating AC power is phase angle control, where the firing angle of a thyristor (SCR/triac) is adjusted to control the portion of the AC waveform delivered to the load. However, phase angle control by itself can lead to overshoot, slow response, or instability when load or input conditions vary.
To overcome these challenges, we propose the integration of a PID (Proportional– Integral– Derivative) controller. The PID algorithm dynamically adjusts the firing angle of the power electronics device based on feedback (such as load voltage, current, or power), ensuring that the output closely follows the desired setpoint. This combination allows us to achieve smooth, accurate, and stable power regulation in AC circuits.

### 1.2 Objectives

- Design and build a safe, isolated circuit for measuring real-time AC voltage and current.
- Implement a phase angle control circuit using a Triac for regulating AC power.
- Integrate these systems with an Arduino microcontroller.
- Implement and tune a PID control algorithm to maintain a precise power setpoint.
- Develop a user interface for setting the target power and viewing system status.

## 2 Methodology

### 2.1 Overview with Major Components

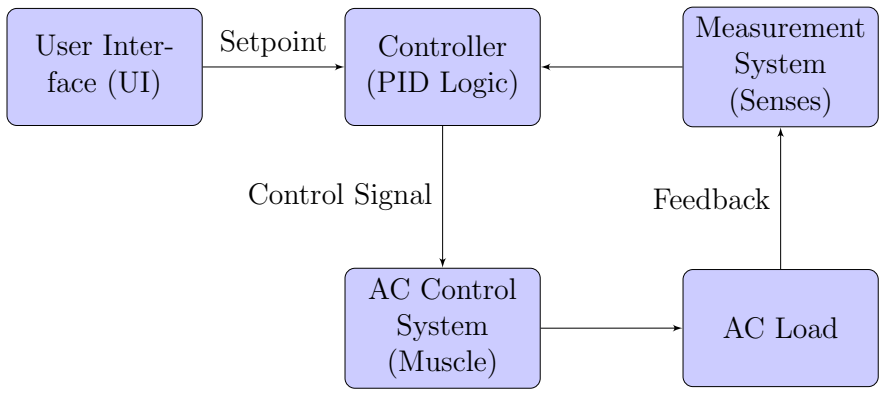
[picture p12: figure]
User Inter- face (UI); Controller (PID Logic); AC Control System (Muscle); Measurement System (Senses); AC Load; Setpoint; Control Signal; Feedback

Figure 1: System Overview of the Closed-Loop Power Controller

### 2.2 Circuit Diagrams

### 2.2.1 User Interface

User Interface Module

16x2 I2C LCD Display

SCL
SDA
VCC (+5V)
GND

Set Point Control Buttons
+5V | UP

D5
R1 10kΩ
+5V | DOWN

To Arduino D6
R2 10kΩ

Arduino Connections
SCL → A5
SDA → A4
UP Button → D5
DOWN Button → D6
VCC → +5V
GND → GND

Figure 2: User Interface Module - LCD Display and Control Buttons

### 2.2.2 AC Control System

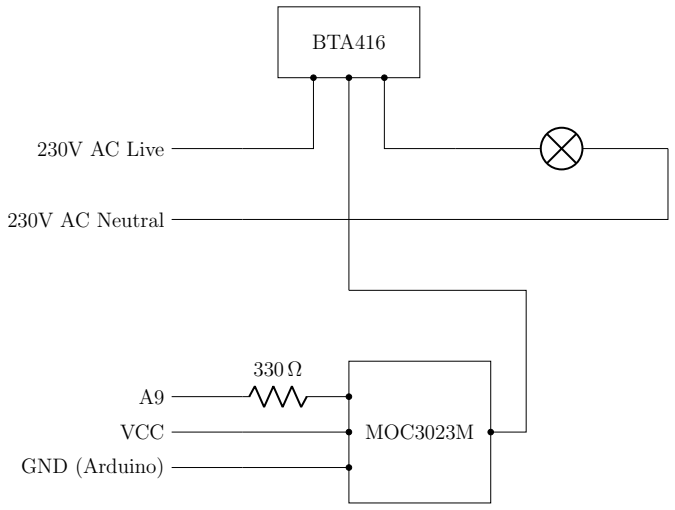
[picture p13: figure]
230V AC Live; 230V AC Neutral; BTA416; VCC; GND (Arduino); MOC3023M

### 2.2.3 Measurement System

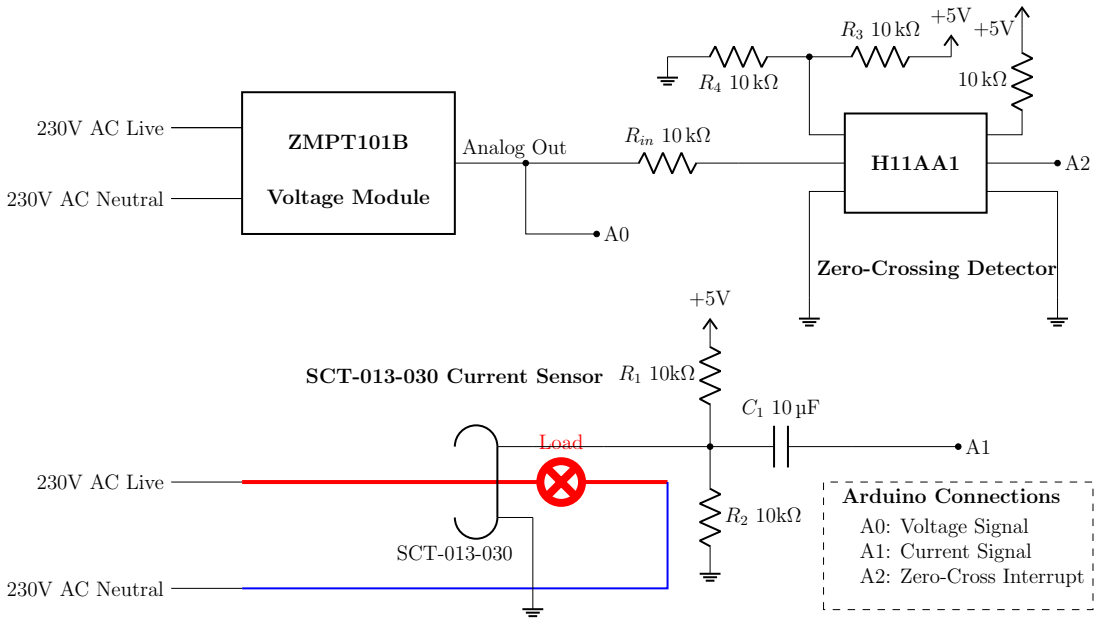
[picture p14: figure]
230V AC Live; 230V AC Neutral; ZMPT101B; Voltage Module; Analog Out; SCT-013-030 Current Sensor; Load; SCT-013-030; Zero-Crossing Detector; Rin 10 kΩ; Arduino Connections; A0: Voltage Signal A1: Current Signal A2: Zero-Cross Interrupt

Figure 3: Measurement and Timing Module Schematic

## 3 Challenges & Troubleshooting strategy

### 3.1 Safety

The project involves working with AC mains supply, which introduces several safety concerns. The foremost challenge is high voltage exposure, since direct contact with live components can cause severe electric shock or injury. To mitigate this, all high-voltage sections are enclosed, and isolation is provided between the control and power circuits. Short circuits and overcurrent conditions are also possible due to load faults or wiring errors, leading to damaging current surges. To counter this, fuses and circuit breakers are employed to protect the circuit from catastrophic failure. Similarly, improper isolation between the high-voltage power stage and the low-voltage control circuitry poses the risk of leakage currents reaching the user or microcontroller. This issue is minimized by using opto-isolators, isolation transformers, and careful PCB layout design.
Another important aspect is the misuse or rating exceedance of components, where devices such as SCRs, triacs, or resistors may fail if operated beyond their current, voltage, or thermal limits. To avoid this, all components are chosen with appropriate safety margins.

### 3.2 PID tuning

Tuning a PID controller for AC power regulation using phase angle control presents several challenges. One of the main difficulties is the nonlinear relationship between firing angle and load power, since PID control generally assumes a linear system model. This mismatch makes it harder to achieve stable tuning. Another issue arises from system delays, particularly with inductive loads, which introduce phase lag and can cause oscil-lations or instability in the response. In addition, there is significant coupling between the parameters Kp, Ki

, and Kd, such that adjusting one parameter often changes the effect of the others, making the tuning process less straightforward. The system is also vulnerable to noise in feedback signals, as voltage and current sensors can pick up switching noise from SCR or triac operations, which is especially problematic for the derivative term that tends to amplify high-frequency noise. Another challenge is integral windup, where prolonged errors cause the integral term to accumulate excessively, leading to overshoot and sluggish recovery. Finally, the controller’s performance can vary significantly under different load types, since gains tuned for resistive loads may not be suitable for inductive loads that respond more slowly.

## 4 Summary

This project undertakes the design and implementation of a Precision Closed-Loop AC Power Controller. Standard open-loop AC control methods, such as simple dimmers, are susceptible to inaccuracies caused by fluctuations in mains voltage and changing load conditions. To overcome this, our system will employ a closed-loop feedback mechanism driven by a Proportional-Integral-Derivative (PID) control algorithm.
The primary objective is to create a robust and stable system capable of maintaining a user-defined power setpoint with high precision, demonstrating a practical application of control theory in modern power electronics. Safety is a paramount design consideration, addressed through galvanic isolation between low-voltage logic and high-voltage power circuits.

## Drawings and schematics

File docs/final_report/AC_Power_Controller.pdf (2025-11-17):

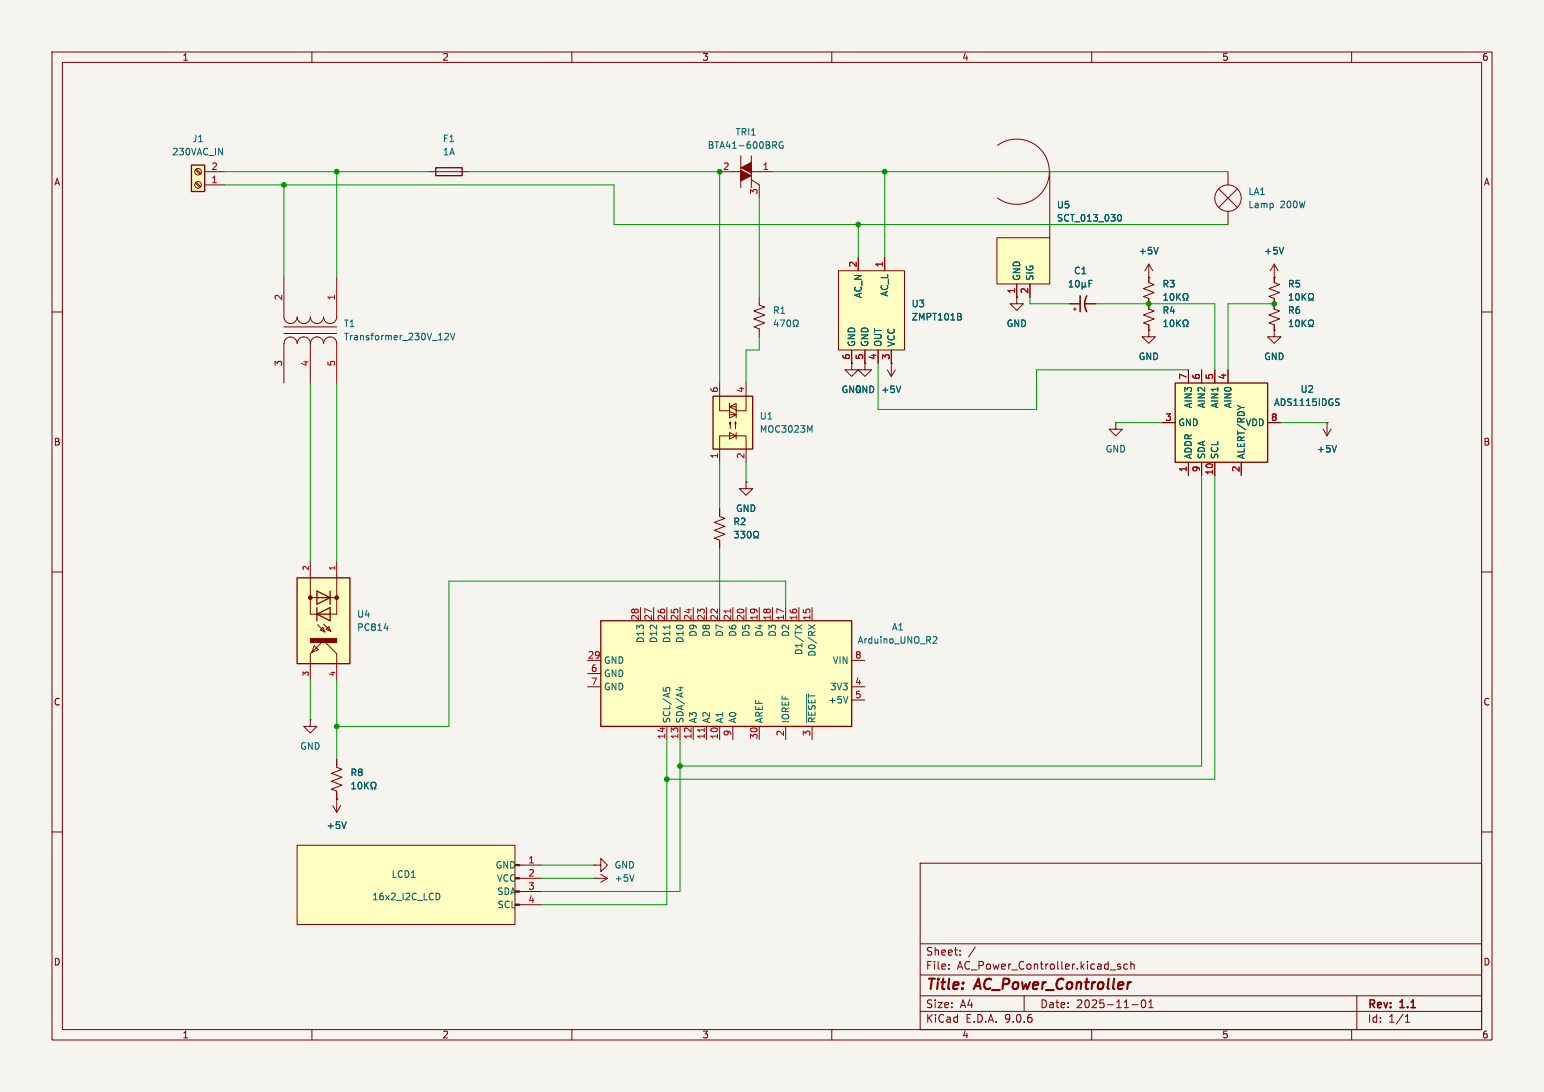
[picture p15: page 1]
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

7 VDD 8 GND 3 ALERT/RDY

Id: 1/1 Title: AC_Power_Controller File: AC_Power_Controller.kicad_sch Sheet: /

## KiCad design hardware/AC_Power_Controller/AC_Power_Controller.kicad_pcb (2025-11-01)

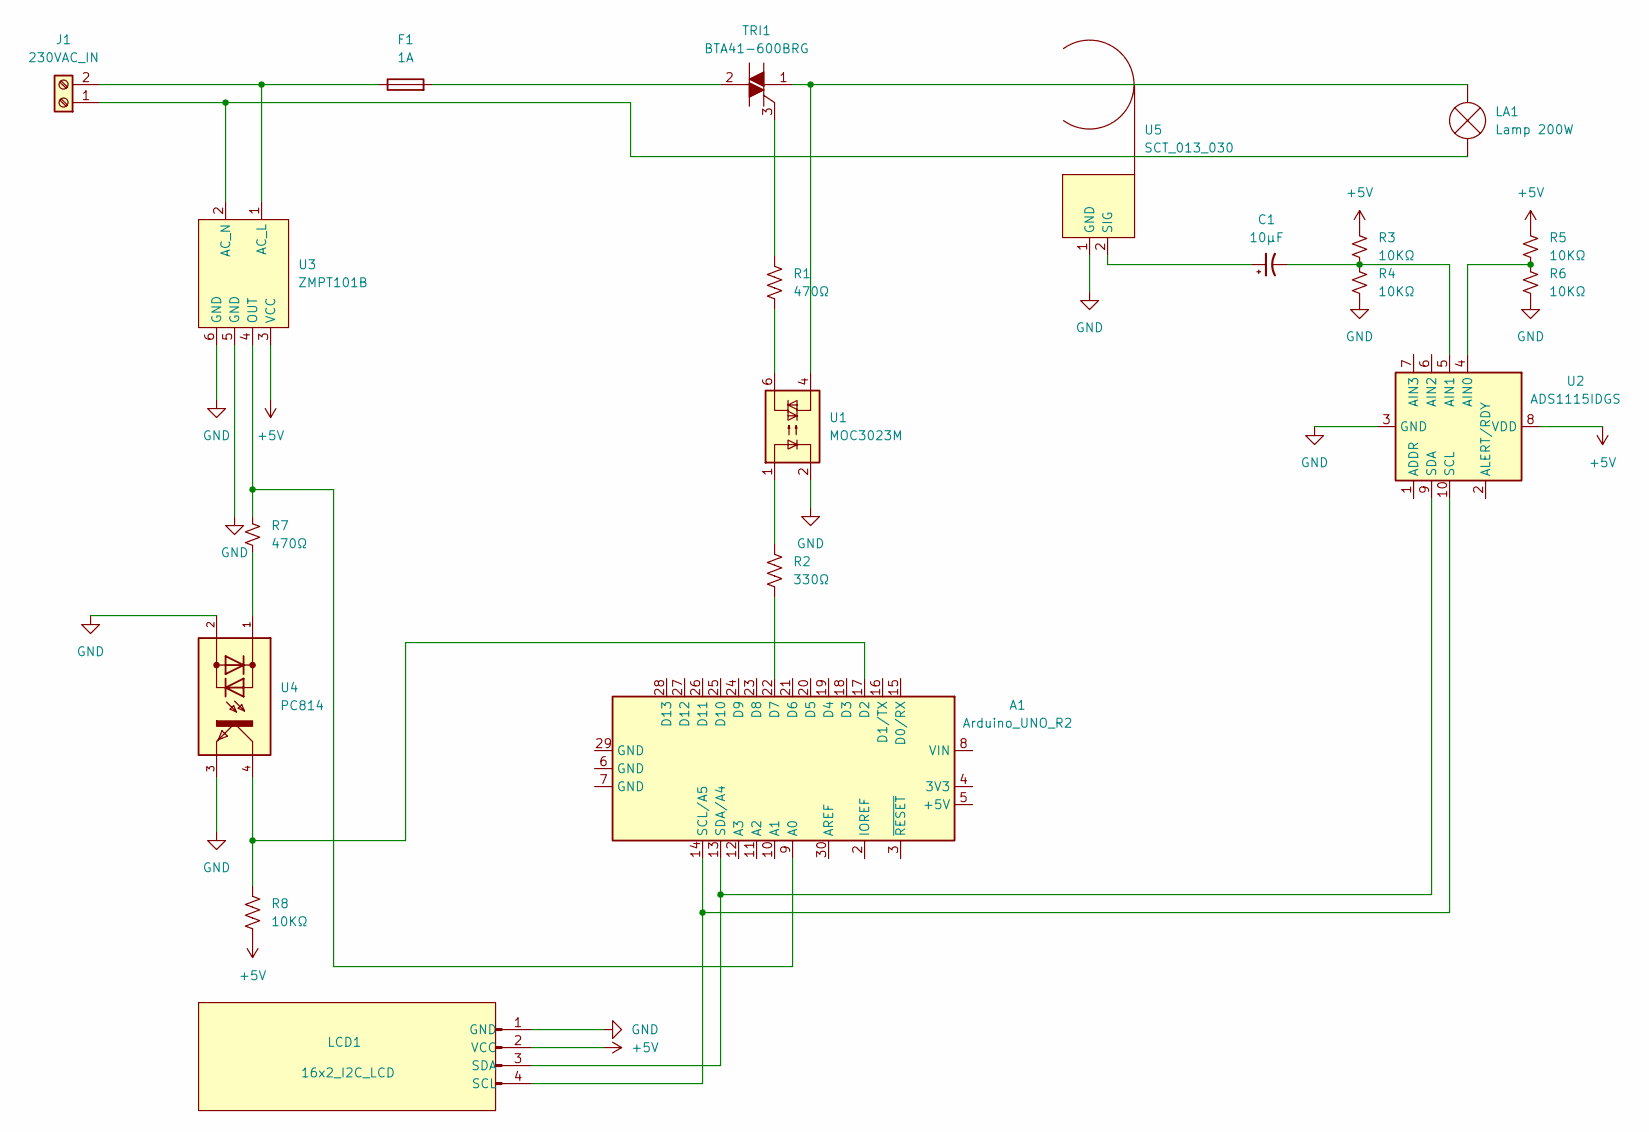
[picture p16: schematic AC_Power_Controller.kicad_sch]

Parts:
A1: Arduino_UNO_R2
C1: 10µF; PinHeader_1x06_P2.54mm_Vertical
F1: 1A; FuseHolder_Blade_ATO_Littelfuse_FLR_178.6165
J1: 230VAC_IN; PinHeader_1x02_P2.54mm_Vertical
LA1: Lamp 200W; PinHeader_1x02_P2.54mm_Vertical
LCD1: 16x2_I2C_LCD; PinHeader_1x04_P2.54mm_Vertical
R1, R7: 470Ω; R_Axial_DIN0204_L3.6mm_D1.6mm_P5.08mm_Horizontal
R2: 330Ω; R_Axial_DIN0204_L3.6mm_D1.6mm_P5.08mm_Horizontal
R3, R4, R5, R6, R8: 10KΩ; R_Axial_DIN0204_L3.6mm_D1.6mm_P5.08mm_Horizontal
TRI1: BTA41-600BRG; TOP-3_Vertical_Insulated; MPN BTA41-600BRG; Digi-Key_PN 497-2431-5-ND
U1: MOC3023M; DIP-6_W7.62mm
U2: ADS1115IDGS; TSSOP-10_3x3mm_P0.5mm
U3: ZMPT101B; PinHeader_1x06_P2.54mm_Vertical
U4: PC814; DIP-4_W10.16mm
U5: SCT_013_030; PinHeader_1x02_P2.54mm_Vertical

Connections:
+5V: LCD1.2 (VCC), R3.1, R5.1, R8.2, U2.8 (VDD), U3.3 (VCC)
GND: LCD1.1 (GND), R4.2, R6.2, U1.2, U2.3 (GND), U3.5 (GND), U3.6 (GND), U4.2, U4.3, U5.1 (GND)
unnamed: A1.9 (A0), R7.1, U3.4 (OUT)
unnamed: A1.17 (D2), R8.1, U4.4
unnamed: A1.22 (D7), R2.2
unnamed: A1.14 (SCL/A5), LCD1.4 (SCL), U2.10 (SCL)
unnamed: A1.13 (SDA/A4), LCD1.3 (SDA), U2.9 (SDA)
unnamed: J1.1, LA1.1 (-), U3.2 (AC_N)
unnamed: F1.1, J1.2, U3.1 (AC_L)
unnamed: LA1.2 (+), TRI1.1 (A1), U1.4
unnamed: R1.2, U1.6
unnamed: R2.1, U1.1
unnamed: R7.2, U4.1
unnamed: F1.2, TRI1.2 (A2)
unnamed: R1.1, TRI1.3 (G)
unnamed: R5.2, R6.1, U2.4 (AIN0)
unnamed: C1.2, R3.2, R4.1, U2.5 (AIN1)
unnamed: C1.1, U5.2 (SIG)

Board: 2 copper layers, 20 parts (0 on the bottom side), 18 nets, no tracks yet.

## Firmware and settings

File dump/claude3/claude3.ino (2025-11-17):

/*
 * AC SENSOR CALIBRATION TOOL - FIXED
 * 
 * Step 1: Calibrate ZMPT101B Voltage Sensor (bulb OFF)
 * Step 2: Calibrate SCT-013-030 Current Sensor (bulb ON at full brightness)
 * 
 * Hardware:
 * - ZMPT101B → ADS1115 A3 (Single-Ended)
 * - SCT-013-030 → ADS1115 A0 (+) and A1 (-) (Differential)
 * - ZCD (PC814) → Pin D2
 * - Triac (MOC3023M) → Pin D7
 */

#include <Wire.h>
#include <Adafruit_ADS1X15.h>

// --- Pin Definitions ---
const int VOLTAGE_ADC_PIN = 3;      // ZMPT101B on A3
const int CURRENT_ADC_DIFF_P = 0;   // SCT-013 on A0
const int CURRENT_ADC_DIFF_N = 1;   // Reference on A1
const int ZCD_PIN = 2;              // PC814 Zero-Cross Detector
const int TRIAC_PIN = 7;            // Triac trigger

// --- ADS1115 Setup ---
Adafruit_ADS1115 ads;
const float ADS_VOLTS_PER_BIT = 0.000125F; // For GAIN_ONE (+/- 4.096V)

// --- Calibration Variables ---
const int SAMPLE_COUNT = 1000;      // Number of samples for RMS
const int CALIBRATION_CYCLES = 5;  // Number of measurement cycles

// --- Triac Control ---
volatile bool zcdFlag = false;
bool triacEnabled = false;
const int ZERO_DELAY = 100;         // Minimal delay for full brightness (microseconds)

// --- Interrupt Service Routine ---
void onZeroCross() {
  zcdFlag = true;
}

void setup() {
  Serial.begin(115200);
  while (!Serial) delay(10);
  
  Serial.println("====================================");
  Serial.println("  AC SENSOR CALIBRATION TOOL");
  Serial.println("====================================");
  Serial.println();
  
  // Initialize ADS1115
  if (!ads.begin()) {
    Serial.println("ERROR: Failed to initialize ADS1115!");
    while (1);
  }
  
  ads.setGain(GAIN_ONE); // +/- 4.096V range
  Serial.println("ADS1115 Initialized (GAIN_ONE: +/- 4.096V)");
  
  // Setup pins
  pinMode(TRIAC_PIN, OUTPUT);
  pinMode(ZCD_PIN, INPUT);
  digitalWrite(TRIAC_PIN, LOW);
  
  // Attach interrupt for zero-cross detection
  attachInterrupt(digitalPinToInterrupt(ZCD_PIN), onZeroCross, RISING);
  
  Serial.println("Hardware Initialized");
  Serial.println();
  delay(2000);
  
  // Start calibration sequence
  runCalibration();
}

void loop() {
  // Handle triac firing if enabled
  if (triacEnabled && zcdFlag) {
    delayMicroseconds(ZERO_DELAY);
    digitalWrite(TRIAC_PIN, HIGH);
    delayMicroseconds(10);
    digitalWrite(TRIAC_PIN, LOW);
    zcdFlag = false;
  }
}

void runCalibration() {
//  Serial.println("====================================");
//  Serial.println("STEP 1: VOLTAGE CALIBRATION");
//  Serial.println("====================================");
//  Serial.println("Instructions:");
//  Serial.println("1. Ensure bulb is OFF (Triac disabled)");
//  Serial.println("2. Connect ZMPT101B to mains voltage");
//  Serial.println("3. Measure actual voltage with multimeter");
//  Serial.println("4. Note the voltage (should be ~230V)");
//  Serial.println();
//  Serial.println("Starting voltage measurement in 5 seconds...");
//  delay(5000);
  
  // Measure voltage with bulb OFF
  calibrateVoltage();
  
  Serial.println();
  Serial.println("====================================");
  Serial.println("STEP 2: CURRENT CALIBRATION");
  Serial.println("====================================");
  Serial.println("Instructions:");
  Serial.println("1. Turning bulb ON at FULL BRIGHTNESS");
  Serial.println("2. Measure actual current with multimeter");
  Serial.println("3. Note the current reading");
  Serial.println();
  Serial.println("Turning bulb ON in 5 seconds...");
  Serial.println("Make sure your multimeter is ready!");
  delay(5000);
  
  // Enable triac for full brightness
  triacEnabled = true;
  
  Serial.println();
  Serial.println("*** BULB IS NOW ON! ***");
  Serial.println("Waiting 3 seconds for bulb to stabilize...");
  delay(3000);
  
  // Measure current with bulb ON
  calibrateCurrent();
  
  // Turn off bulb
  triacEnabled = false;
  digitalWrite(TRIAC_PIN, LOW);
  
  Serial.println();
  Serial.println("*** BULB TURNED OFF ***");
  Serial.println();
  Serial.println("====================================");
  Serial.println("CALIBRATION COMPLETE!");
  Serial.println("====================================");
  Serial.println("You can now use the calibration");
  Serial.println("constants in your main code.");
  Serial.println();
  
  while(1); // Stop here
}

void calibrateVoltage() {
  Serial.println("--- Voltage Calibration Measurements ---");
  Serial.println();
  
  double totalRawRMS = 0;
  
  for (int cycle = 0; cycle < CALIBRATION_CYCLES; cycle++) {
    long sumVoltageSq = 0;
    int16_t voltageOffset = findVoltageOffset();
    
    // Sample voltage
    for (int i = 0; i < SAMPLE_COUNT; i++) {
      int16_t voltageSample = ads.readADC_SingleEnded(VOLTAGE_ADC_PIN);
      unsigned long long filteredVoltage = voltageSample - voltageOffset;
      sumVoltageSq += filteredVoltage * filteredVoltage;
      delayMicroseconds(100);
    }
    
    // Calculate RMS
    double meanVoltageSq = (double)sumVoltageSq / SAMPLE_COUNT;
    double rmsVoltageRaw = sqrt(meanVoltageSq);
    totalRawRMS += rmsVoltageRaw;
    
    double rmsVoltageVolts = rmsVoltageRaw * ADS_VOLTS_PER_BIT;
    
    Serial.print("Cycle "); Serial.print(cycle + 1);
    Serial.print(": Raw RMS = "); Serial.print(rmsVoltageRaw, 2);
    Serial.print(" counts, Voltage = "); Serial.print(rmsVoltageVolts, 4);
    Serial.println(" V");
    
    delay(500);
  }
  
  double avgRawRMS = totalRawRMS / CALIBRATION_CYCLES;
  double avgVoltageVolts = avgRawRMS * ADS_VOLTS_PER_BIT;
  
  Serial.println();
  Serial.println("--- Voltage Calibration Results ---");
  Serial.print("Average Raw RMS: "); Serial.print(avgRawRMS, 2); Serial.println(" counts");
  Serial.print("Average Voltage: "); Serial.print(avgVoltageVolts, 4); Serial.println(" V");
  Serial.println();
  
//  Serial.println("TO CALIBRATE:");
//  Serial.println("1. Measure actual mains voltage with multimeter (e.g., 230V)");
//  Serial.println("2. Calculate: VOLTAGE_CAL = (Your_Multimeter_Reading) / " + String(avgVoltageVolts, 4));
//  Serial.println();
//  Serial.print("Example: If multimeter shows 230V, then VOLTAGE_CAL = 230 / ");
//  Serial.print(avgVoltageVolts, 4);
//  Serial.print(" = ");
//  Serial.println(230.0 / avgVoltageVolts, 2);
//  Serial.println();
//  
  // Wait before next step
  delay(3000);
}

void calibrateCurrent() {
  Serial.println("--- Current Calibration Measurements ---");
  Serial.println("Bulb should be ON and bright now!");
  Serial.println();
  
  double totalRawRMS = 0;
  
  for (int cycle = 0; cycle < CALIBRATION_CYCLES; cycle++) {
    long sumCurrentSq = 0;
    
    // Sample current (differential reading) - with small delays to allow triac firing
    for (int i = 0; i < SAMPLE_COUNT; i++) {
      int16_t currentSample = ads.readADC_Differential_0_1();
      sumCurrentSq += (long)currentSample * (long)currentSample;
      
      // Very short delay to allow loop() to keep firing triac
      delayMicroseconds(50);
    }
    
    // Calculate RMS
    double meanCurrentSq = (double)sumCurrentSq / SAMPLE_COUNT;
    double rmsCurrentRaw = sqrt(meanCurrentSq);
    totalRawRMS += rmsCurrentRaw;
    
    double rmsCurrentVolts = rmsCurrentRaw * ADS_VOLTS_PER_BIT;
    
    Serial.print("Cycle "); Serial.print(cycle + 1);
    Serial.print(": Raw RMS = "); Serial.print(rmsCurrentRaw, 2);
    Serial.print(" counts, Signal = "); Serial.print(rmsCurrentVolts, 4);
    Serial.println(" V");
    
    // Short delay between cycles
    delay(200);
  }
  
  double avgRawRMS = totalRawRMS / CALIBRATION_CYCLES;
  double avgCurrentVolts = avgRawRMS * ADS_VOLTS_PER_BIT;
  
  Serial.println();
  Serial.println("--- Current Calibration Results ---");
  Serial.print("Average Raw RMS: "); Serial.print(avgRawRMS, 2); Serial.println(" counts");
  Serial.print("Average Signal: "); Serial.print(avgCurrentVolts, 4); Serial.println(" V");
  Serial.println();
  
  Serial.println("TO CALIBRATE:");
  Serial.println("1. Measure actual current with multimeter (e.g., 0.26A for 60W bulb)");
  Serial.println("2. Calculate: CURRENT_CAL = (Your_Multimeter_Reading) / " + String(avgRawRMS, 2));
  Serial.println();
  Serial.print("Example: If multimeter shows 0.26A, then CURRENT_CAL = 0.26 / ");
  Serial.print(avgRawRMS, 2);
  Serial.print(" = ");
  
  if (avgRawRMS > 0) {
    Serial.println(0.26 / avgRawRMS, 6);
  } else {
    Serial.println("ERROR - No current detected!");
    Serial.println();
    Serial.println("TROUBLESHOOTING:");
    Serial.println("- Check if bulb is actually ON (visually confirm)");
    Serial.println("- Check ZCD signal on Pin D2 (should pulse)");
    Serial.println("- Check Triac connection to Pin D7");
    Serial.println("- Verify SCT-013-030 is clamped around the wire");
    Serial.println("- Check ADS1115 connections (A0 and A1)");
  }
  Serial.println();
}

int16_t findVoltageOffset() {
  // Find DC offset by averaging multiple samples
  long sum = 0;
  const int offsetSamples = 100;
  
  for (int i = 0; i < offsetSamples; i++) {
    sum += ads.readADC_SingleEnded(VOLTAGE_ADC_PIN);
    delayMicroseconds(100);
  }
  
  return sum / offsetSamples;
}

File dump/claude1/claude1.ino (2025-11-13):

#include <Wire.h>
#include <Adafruit_ADS1X15.h>
#include <LiquidCrystal_I2C.h>

// --- I2C Addresses ---
LiquidCrystal_I2C lcd(0x27, 16, 2);

// --- ADS1115 Setup ---
Adafruit_ADS1115 ads;

// --- Pin Definitions ---
const int ZCD_PIN = 2;       // PC814 ZCD
const int TRIAC_PIN = 7;     // MOC3023M trigger

// --- ADS Channels (ALL SINGLE-ENDED) ---
const int CURRENT_ADC_PIN = 0;     // A0 - SCT-013-030
const int VREF_ADC_PIN = 1;        // A1 - 2.5V Reference
const int VOLTAGE_ADC_PIN = 3;     // A3 - ZMPT101B

// --- ADS Settings ---
const float ADS_VOLTS_PER_BIT = 0.000125F; // For GAIN_ONE (+/- 4.096V)

// --- Calibration Values ---
int voltageOffset = 0;        // DC offset for voltage
int currentOffset = 0;        // DC offset for current
int vrefOffset = 0;           // Reference offset
double VOLTAGE_CAL = 155.0;   // Voltage scaling factor
double CURRENT_CAL = 30.0;    // Current scaling factor (30A/1V for SCT-013-030)

// --- Bulb Control ---
const int BULB_FIRING_DELAY = 1000; // Low delay = bright bulb for current testing
volatile bool zcdFlag = false;
bool bulbEnabled = false;

// --- Measurement Variables ---
const int sampleCount = 500;
float voltage_rms = 0;
float current_rms = 0;
float power = 0;
float vref_voltage = 0;

// --- Timing ---
unsigned long lastMeasurement = 0;
const int MEASUREMENT_INTERVAL = 1000;

// --- Calibration State Machine ---
enum CalState { 
  IDLE,
  OFFSET_CAL_WAIT,
  OFFSET_CAL_RUNNING,
  VOLTAGE_CAL_WAIT,
  VOLTAGE_CAL_RUNNING,
  CURRENT_CAL_WAIT,
  CURRENT_CAL_RUNNING,
  MEASUREMENT_MODE
};
CalState calState = IDLE;

// --- ZCD Interrupt ---
void onZeroCross() {
  zcdFlag = true;
}

void setup() {
  Serial.begin(9600);
  
  // Initialize Triac control
  pinMode(TRIAC_PIN, OUTPUT);
  pinMode(ZCD_PIN, INPUT);
  digitalWrite(TRIAC_PIN, LOW);
  attachInterrupt(digitalPinToInterrupt(ZCD_PIN), onZeroCross, RISING);
  
  // Initialize LCD
  lcd.init();
  lcd.backlight();
  lcd.clear();
  lcd.setCursor(0, 0);
  lcd.print(F("Power Monitor"));
  lcd.setCursor(0, 1);
  lcd.print(F("Initializing..."));
  
  // Initialize ADS1115
  if (!ads.begin()) {
    Serial.println(F("Failed to initialize ADS1115!"));
    lcd.clear();
    lcd.print(F("ADS Error!"));
    while (1);
  }
  
  // Set gain to GAIN_ONE (+/- 4.096V) - SINGLE-ENDED MODE ONLY
  ads.setGain(GAIN_ONE);
  
  delay(2000);
  lcd.clear();
  
  Serial.println(F("   AC POWER MONITOR - CALIBRATION"));
  Serial.println(F("\nType 'START' to begin calibration"));
  Serial.println(F("Type 'MEASURE' to skip to measurement mode"));
}

void loop() {
  // Handle bulb control (if enabled)
  if (bulbEnabled && zcdFlag) {
    delayMicroseconds(BULB_FIRING_DELAY);
    digitalWrite(TRIAC_PIN, HIGH);
    delayMicroseconds(10);
    digitalWrite(TRIAC_PIN, LOW);
    zcdFlag = false;
  }
  
  // Check for serial commands
  if (Serial.available()) {
    String cmd = Serial.readStringUntil('\n');
    cmd.trim();
    cmd.toUpperCase();
    handleCommand(cmd);
  }
  
  // Run calibration state machine
  if (millis() - lastMeasurement >= MEASUREMENT_INTERVAL) {
    runCalibrationStateMachine();
    lastMeasurement = millis();
  }
}

void handleCommand(String cmd) {
  if (cmd == "START" || cmd == "S") {
    calState = OFFSET_CAL_WAIT;
    bulbEnabled = false;
    digitalWrite(TRIAC_PIN, LOW);
  } else if (cmd == "MEASURE" || cmd == "M") {
    calState = MEASUREMENT_MODE;
    Serial.println(F("\n=== MEASUREMENT MODE ==="));
    Serial.println(F("Type 'BULB ON' or 'BULB OFF' to control bulb"));
  } else if (cmd == "BULB ON") {
    bulbEnabled = true;
    Serial.println(F("Bulb: ON"));
  } else if (cmd == "BULB OFF") {
    bulbEnabled = false;
    digitalWrite(TRIAC_PIN, LOW);
    Serial.println(F("Bulb: OFF"));
  } else if (cmd == "NEXT" || cmd == "N") {
    // Advance to next calibration step
    if (calState == OFFSET_CAL_RUNNING) {
      calState = VOLTAGE_CAL_WAIT;
    } else if (calState == VOLTAGE_CAL_RUNNING) {
      calState = CURRENT_CAL_WAIT;
    } else if (calState == CURRENT_CAL_RUNNING) {
      calState = MEASUREMENT_MODE;
    }
  } else if (cmd.startsWith(F("VCAL="))) {
    // Manual voltage calibration: VCAL=230
    double actualVoltage = cmd.substring(5).toDouble();
    if (actualVoltage > 0 && voltage_rms > 0) {
      VOLTAGE_CAL = VOLTAGE_CAL * (actualVoltage / voltage_rms);
      Serial.print(F("New VOLTAGE_CAL: ")); Serial.println(VOLTAGE_CAL, 2);
    }
  } else if (cmd.startsWith(F("ICAL="))) {
    // Manual current calibration: ICAL=2.5
    double actualCurrent = cmd.substring(5).toDouble();
    if (actualCurrent > 0 && current_rms > 0) {
      CURRENT_CAL = CURRENT_CAL * (actualCurrent / current_rms);
      Serial.print(F("New CURRENT_CAL: ")); Serial.println(CURRENT_CAL, 5);
    }
  }
}
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

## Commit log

2025-10-21 Create PID code
    Bhaiyo is code ka use kare,
2025-10-21 Update PID code
2025-10-31 added schematics
    [AC_Power_Controller.kicad_pcb, AC_Power_Controller.kicad_sch, Arduino_Power_Controller.kicad_sch]
2025-11-01 minors changes to schematics
    [AC_Power_Controller.kicad_pcb, AC_Power_Controller.kicad_sch]
2025-11-01 corrections to schematics
    [AC_Power_Controller.kicad_pcb, AC_Power_Controller.kicad_sch]
2025-11-06 schematic corrections
    [AC_Power_Controller.kicad_sch]
2025-11-12 Add phase-angle PID control with ADS1115
    Implement phase-angle PID control with ADS1115 and LCD display for voltage and current measurements.
2025-11-13 done, please, final code with fixes, looper & dimmer works
    [bulb_test.ino, claude.ino, claude1.ino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]
